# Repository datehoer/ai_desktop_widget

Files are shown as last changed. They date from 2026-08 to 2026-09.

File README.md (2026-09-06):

# Codex Usage Widget

**English** | [简体中文](README.zh-CN.md)

A desktop Codex status display built with an ESP32-S3 NANO and a 1.54-inch ST7789 TFT. Track weekly usage, active tasks, and room conditions; enjoy a graffiti-style **HH:MM:SS flip clock** when your tasks are done.

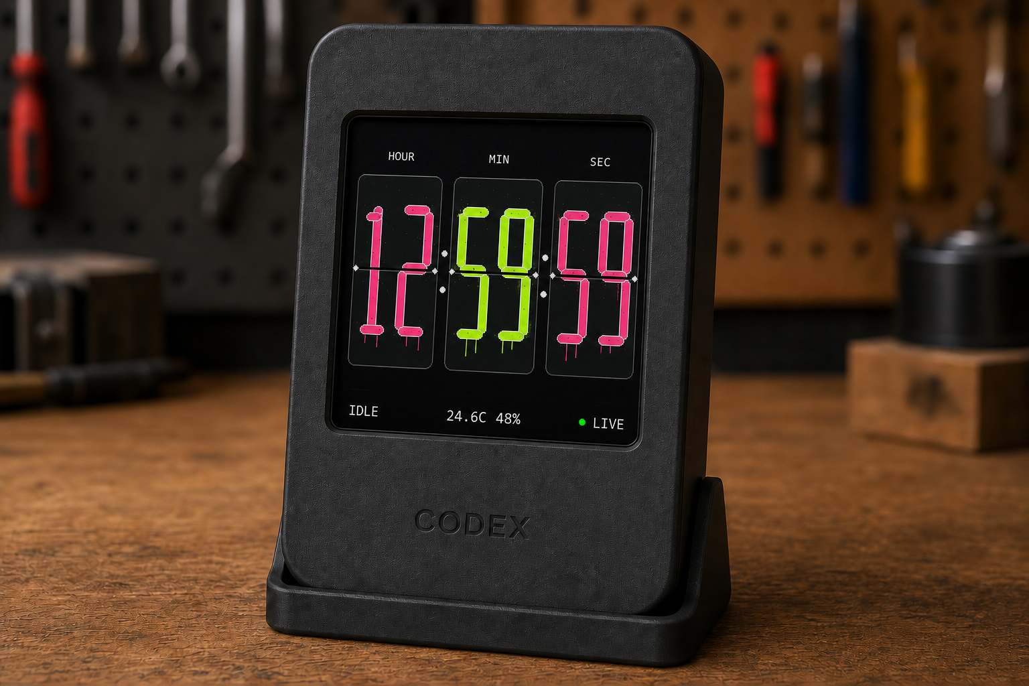
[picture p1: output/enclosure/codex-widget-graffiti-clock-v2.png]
Codex Usage Widget with the three-pair HH:MM:SS flip clock


*AI-generated product concept render of the updated clock interface. The animation preview below is generated from the firmware drawing code; neither image is a photograph of the running device.*

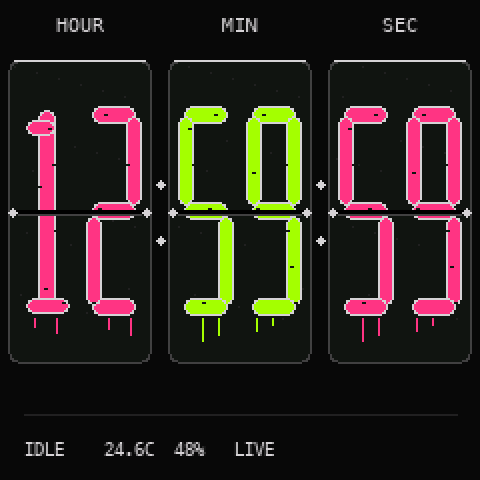
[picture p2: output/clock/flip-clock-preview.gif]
Flip animation generated from the firmware drawing code


The seconds card flips every second. The hour and minute cards join in when their values change. Each flip takes about **650 ms**: the old upper half folds toward the hinge, then the new lower half unfolds with changing shading. Frames are composed in memory before reaching the display. Bridge requests run in a background task so HTTP timeouts do not freeze the clock.

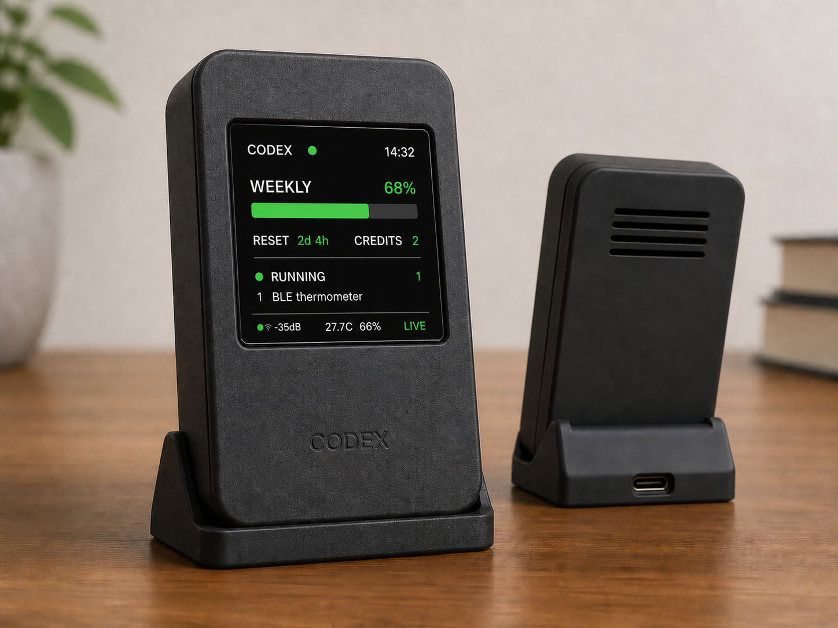
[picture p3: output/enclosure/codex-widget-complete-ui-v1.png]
Task status and BLE room readings, product concept render


## Features

- Weekly Codex usage, reset countdown, and available reset credits.
- Active task count and up to two real task titles, including common Simplified Chinese characters.
- Three paired flip cards for hours, minutes, and seconds, with pink and lime graffiti numerals.
- Automatic switching between the task dashboard, idle clock, and offline clock.
- Temperature and humidity from an optional Xiaomi `LYWSD03MMC` BLE thermometer.
- Wi-Fi setup and later configuration from a browser, with settings saved in NVS.
- A macOS background service that waits for external project volumes and the configured proxy at login.
- Printable enclosure files and a local 3D viewer with mesh diagnostics, assembly inspection, and collision simulation.

The hardware has been tested with an **ESP32-S3 NANO with 16 MB flash and 8 MB PSRAM**, and a **240×240 ST7789 SPI display**. The setup guide below targets macOS.

## Recent changes

| Area | Current behavior |
| --- | --- |
| Flip clock | HH:MM:SS replaces the four-digit HH:MM layout; actual half-page projection replaces the old covering-band transition. |
| Rendering | A 650 ms animation updates changed cards from offscreen buffers; HTTP requests execute separately from rendering. |
| Timekeeping | Minute, hour, and midnight rollovers flip together. Initial NTP sync and clock jumps snap to the current time without replaying missed seconds. |
| Offline fallback | After at least 30 seconds without fresh data and a confirmed request failure, the display switches to `CLOCK / STALE`. Invalid or stale HTTP 200 payloads do not count as recovery. |
| Task tracking | Unfinished rollout activity expires after 30 minutes without file updates by default, preventing abandoned tasks from remaining active indefinitely. |
| Reset countdown | Refreshes independently after time synchronization instead of waiting for the next full status render. |
| Enclosure and viewer | The v7 rear shell repairs non-manifold rail stops; the viewer checks mesh topology and provides an aligned front/rear shell inspection with electronics proxies. |

## How it works

The ESP32 does not sign in to Codex or store ChatGPT credentials. A Node.js bridge on the Mac starts a local `codex app-server`, reads account and task information, and exposes a compact LAN HTTP endpoint. The device polls every **5 seconds by default**, configurable from 2 to 60 seconds.

```mermaid
flowchart LR
    A["Codex Desktop / CLI"] --> B["codex app-server"]
    B --> C["Mac Node.js bridge :8787"]
    C -->|"Wi-Fi / JSON"| D["ESP32-S3 NANO"]
    D -->|"SPI"| E["ST7789 240×240 TFT"]
    F["LYWSD03MMC thermometer"] -->|"BLE"| D
```

The bridge uses `account/rateLimits/read` for quota windows, reset times, and credits, and `thread/list` for task metadata and local rollout paths. It reads rollout lifecycle events to determine whether a task is still running. The HTTP endpoint serves its latest snapshot immediately while refreshing Codex data in the background.

References: [Codex CLI documentation](https://learn.chatgpt.com/docs/codex/cli) and [Codex App Server documentation](https://learn.chatgpt.com/docs/app-server).

## Display modes

| Display | Trigger | Meaning |
| --- | --- | --- |
| Task dashboard · `LIVE` | Valid fresh status with `runningCount > 0` | Shows quota and active tasks. |
| Flip clock · `IDLE / LIVE` | Valid fresh status with `runningCount == 0` | No task is currently executing; the bridge is connected. |
| Existing display · `STALE` | A request fails or returns invalid/stale data | Temporarily retains the previous display while retrying. |
| Flip clock · `CLOCK / STALE` | No fresh status for at least 30 seconds, with failure confirmed | Offline fallback; time and BLE readings remain available after initial clock sync. |
| `NO DATA` | No successful status received yet | Waits for the bridge; persistent failure leads to the offline clock. |
| `SETUP MODE` | Missing configuration, startup Wi-Fi failure, or holding BOOT for 4 seconds | Opens the configuration hotspot. |

**`IDLE` means idle, not disconnected.** A completed assistant reply can leave no running task and switch the display to the clock. A new running task brings back the dashboard on a subsequent refresh. Bridge refresh and device polling each have their own interval, so a change is not instantaneous.

The 30-second fallback uses a monotonic timer. Merely waiting for a configured 60-second poll does not count as a failure. Detection can occur later than 30 seconds if a request is still pending or the next poll has not started. Responses with `ok=false`, `stale=true`, or an invalid task count cannot revive stale tasks.

NTP establishes the clock initially. After that, it keeps time if connectivity is lost; before initial sync, the clock shows placeholders. Time jumps are applied directly. The existing startup Wi-Fi recovery flow still enters setup mode if the configured network cannot be reached.

## 1. Requirements

### Hardware

- ESP32-S3 NANO with soldered headers, 16 MB flash, and 8 MB PSRAM.
- 1.54-inch TFT with ST7789 driver, SPI interface, 240×240 resolution, and soldered headers.
- Eight female-to-female jumper wires.
- A USB-C cable that supports data transfer.
- Optional breadboard; direct jumper connections work for initial testing.
- Optional Xiaomi `LYWSD03MMC` BLE thermometer; no additional wiring is required.

The pin assignment and flash settings match this hardware. Adjust [firmware/platformio.ini](firmware/platformio.ini) for a different board, flash size, display driver, or resolution.

### Software

- macOS, Git, Node.js, npm, Python 3.12, and [uv](https://docs.astral.sh/uv/).
- Node.js 20 or later for the bridge; `.nvmrc` pins **22.22.1** for the project, including the viewer tooling.
- Codex CLI installed and signed in with ChatGPT.
- A 2.4 GHz Wi-Fi network that allows the Mac and ESP32 to reach each other.

## 2. Wire the display with power disconnected

Disconnect USB before wiring. Check every connection before powering the board.

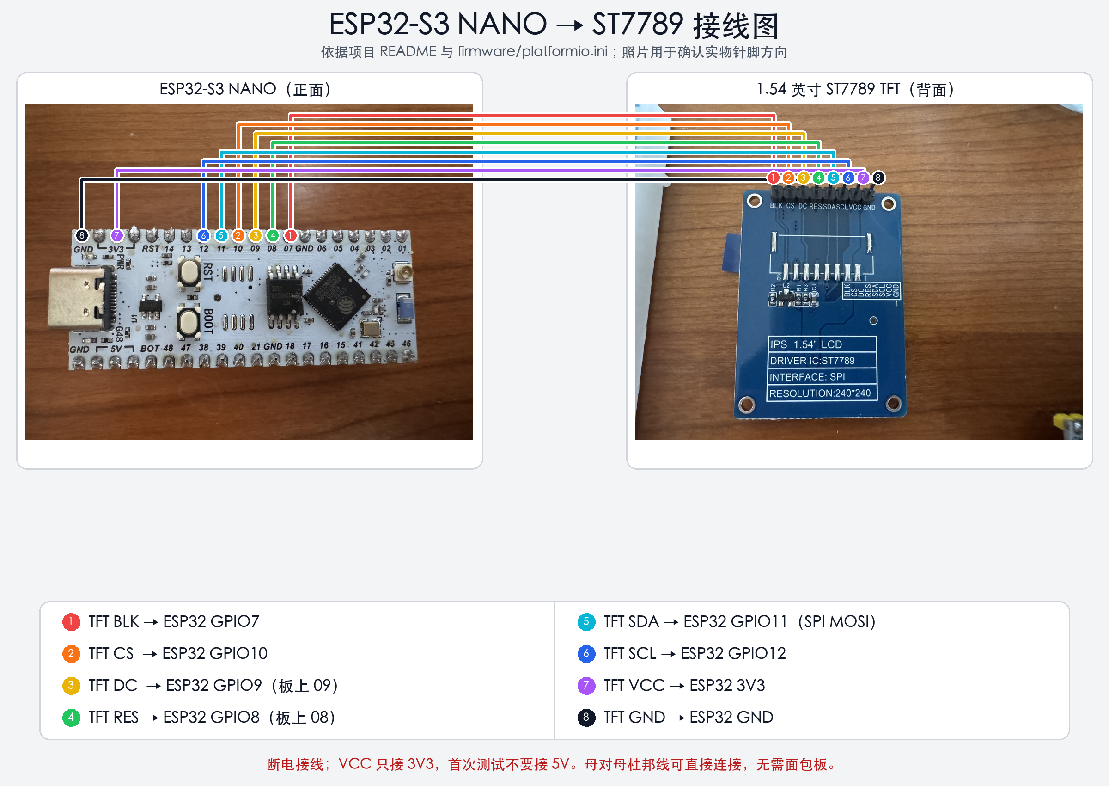
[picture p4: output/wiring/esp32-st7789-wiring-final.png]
ESP32-S3 NANO to ST7789 wiring


| ST7789 TFT | ESP32-S3 NANO | Function |
| --- | --- | --- |
| `BLK` | `GPIO7` | Backlight |
| `CS` | `GPIO10` | SPI chip select |
| `DC` | `GPIO9` | Data/command; printed as `09` on the board |
| `RES` | `GPIO8` | Display reset; printed as `08` |
| `SDA` | `GPIO11` | SPI MOSI, not I²C SDA |
| `SCL` | `GPIO12` | SPI clock |
| `VCC` | `3V3` | 3.3 V supply |
| `GND` | `GND` | Ground |

Connect `VCC` to `3V3`. Verify the actual silkscreen rather than assuming the pin order from viewing direction. Insert connectors fully and check for loose contacts. Wire colors do not determine their function.

## 3. Get the project

```bash
git clone https://github.com/datehoer/ai_desktop_widget.git ai_desktop_usage_widget
cd ai_desktop_usage_widget
```

For a ZIP download, extract it and enter the directory containing `README.md`, `package.json`, and `firmware/`.

```text
ai_desktop_usage_widget/
├── README.md                    # English guide
├── README.zh-CN.md              # Simplified Chinese guide
├── bridge/
│   ├── src/                     # Mac bridge and rollout tracking
│   └── test/                    # Node.js tests
├── firmware/
│   ├── include/
│   │   ├── flip_clock.h         # Portable animation geometry and time transitions
│   │   └── secrets.example.h    # Optional legacy configuration migration
│   ├── src/
│   │   ├── main.cpp             # TFT UI and background status worker
│   │   ├── ble_thermometer.cpp  # BLE sensor reader
│   │   ├── device_config.cpp    # NVS persistence and time zones
│   │   └── config_portal.cpp    # Hotspot and LAN configuration pages
│   ├── test/                   # Native flip-clock tests
│   └── platformio.ini
├── viewer/                     # Local model / G-code viewer and mesh diagnostics
├── output/
│   ├── clock/                  # Firmware-rendered animation preview
│   ├── enclosure/              # OpenSCAD, STL, and product renders
│   └── wiring/                 # Wiring illustration
├── scripts/                    # macOS background service helpers
├── package.json
├── pyproject.toml
└── uv.lock
```

## 4. Check Codex CLI

If needed, install with the macOS/Linux command from the [official Codex CLI guide](https://learn.chatgpt.com/docs/codex/cli):

```bash
curl -fsSL https://chatgpt.com/codex/install.sh | sh
```

Then verify and sign in:

```bash
codex --version
codex
```

Sign in with ChatGPT if needed, exit the interactive session, and check that App Server starts:

```bash
codex app-server
```

If the process stays running without an immediate error, stop it with `Ctrl+C`. The bridge starts its own instance, so a second manually started instance is unnecessary.

## 5. Prepare Node.js

With nvm installed:

```bash
nvm install
nvm use
node --version
npm --version
npm test
```

The bridge uses only Node.js built-in modules and has no third-party npm runtime dependencies. The separate viewer has its own dependencies.

## 6. Start the Mac bridge

```bash
npm start
```

Example output:

```text
Codex Usage Bridge listening on http://0.0.0.0:8787
ESP32 URL: http://192.168.1.100:8787/api/status
```

Use the printed **LAN IPv4 URL** in the device configuration. `localhost` and `127.0.0.1` refer to the ESP32 itself when entered on the device.

Leave the bridge running and check it from another terminal:

```bash
curl http://127.0.0.1:8787/healthz
curl http://127.0.0.1:8787/api/status
```

A successful status includes fields such as these; values are illustrative:

```json
{
  "ok": true,
  "stale": false,
  "quota": {
    "weekly": {
      "usedPercent": 7,
      "resetsAt": 1780000000
    }
  },
  "resetCredits": 0,
  "runningCount": 1,
  "running": [
    { "title": "Build the desktop widget" }
  ]
}
```

### Bridge environment variables

| Variable | Default | Purpose |
| --- | --- | --- |
| `PORT` | `8787` | HTTP port |
| `HOST` | `0.0.0.0` | HTTP bind address |
| `REFRESH_MS` | `5000` | Background refresh interval in milliseconds |
| `RUNNING_STALE_MS` | `1800000` | Expire active rollouts after this period without file updates; `0` disables expiry |
| `CODEX_BIN` | `codex` | Custom Codex CLI path |
| `DEBUG_CODEX_BRIDGE` | Unset | Set to `1` to show App Server logs |

## 7. Prepare Python and PlatformIO

uv manages Python 3.12 and the pinned PlatformIO **6.1.19** environment:

```bash
uv sync
uv run platformio --version
```

This creates `.venv`; a separate Conda environment is unnecessary.

If dependency downloads require a local proxy, configure it in the current terminal, using your own address:

```bash
export https_proxy=http://127.0.0.1:7890
export http_proxy=http://127.0.0.1:7890
export all_proxy=http://127.0.0.1:7890
export no_proxy=
uv sync
uv run platformio run -d firmware
```

After downloading, use a clean terminal or appropriate proxy bypass settings for LAN traffic.

## 8. Prepare first-time configuration

Wi-Fi credentials are configured in a browser and stored in NVS. A new device does not need `secrets.h`. Prepare:

- Your 2.4 GHz Wi-Fi SSID and password.
- The Mac bridge LAN URL, such as `http://192.168.1.100:8787/api/status`.
- A time zone; choose the Shanghai / UTC+8 option for China.
- A polling interval from 2 to 60 seconds; the default is 5 seconds.

The setup screen shows:

```text
SETUP MODE
Codex-Widget-XXXX
Password: codexsetup
192.168.4.1
```

Connect a phone or computer to this temporary hotspot. Open the captive portal, or visit `http://192.168.4.1/` manually. Save the configuration to reboot the device.

The setup page currently uses Chinese labels. Existing devices with legacy `secrets.h` settings can connect once and migrate those settings into NVS automatically.

## 9. Identify the connected ESP32

Use a data-capable USB-C cable, then list ports:

```bash
uv run platformio device list
```

A macOS port may look like `/dev/cu.usbmodem11201`; substitute your actual port in all later commands. A power LED alone does not confirm that the firmware is running.

When multiple ESP32 boards are attached, match the USB serial number and startup log. This project prints **`[boot] Codex Usage Widget`**. Do not select a board solely by port numbering or the shared `USB JTAG/serial debug unit` description.

## 10. Build and test the firmware

```bash
uv run platformio run -d firmware
```

The first build downloads TFT_eSPI, ArduinoJson, and U8g2_for_TFT_eSPI, including the compiled WenQuanYi Chinese font.

The current build uses approximately **21.7% static RAM** and **26.7% flash**. Flip buffers allocate another **150 KiB at runtime**, preferably in PSRAM. If buffer allocation fails, the clock falls back to static updates and reports it in the serial log.

Run the portable animation tests on the Mac with a C++ compiler installed:

```bash
c++ -std=c++11 -Wall -Wextra -Werror -Ifirmware/include \
  firmware/test/flip_clock_test.cpp -o /tmp/flip-clock-test
/tmp/flip-clock-test
```

These check page geometry, every daily second rollover, midnight, time jumps, and RGB565 shading.

## 11. Upload the firmware

Specify the verified target port:

```bash
uv run platformio run -d firmware \
  --target upload \
  --upload-port /dev/cu.usbmodem11201
```

A successful upload ends with messages such as:

```text
Hash of data verified.
Hard resetting via RTS pin...
[SUCCESS]
```

If it remains at `Connecting...`, hold **BOOT**, briefly press **RST**, release **BOOT**, and retry.

The project also includes a USB-JTAG recovery environment:

```bash
uv run platformio run -d firmware \
  -e esp32-s3-nano-jtag \
  --target upload
```

## 12. Read the serial log

```bash
uv run platformio device monitor \
  --port /dev/cu.usbmodem11201 \
  --baud 115200
```

Typical output:

```text
[boot] Codex Usage Widget
[boot] initialising TFT on SPI3/HSPI
[boot] TFT ready
[clock] HH:MM:SS flip buffers ready, duration 650ms
[config] loaded from NVS
[wifi] configured SSID found: your-wifi (-42 dBm)
[wifi] connected: 192.168.1.155
[config] bridge: http://192.168.1.100:8787/api/status
[config] hold BOOT for 4s to reconfigure
[display] live status
[task] title: Build the desktop widget
[ble] thermometer reader started
```

Press `Ctrl+C` to leave the monitor. This does not stop the ESP32.

## 13. Read the dashboard and room sensor

The initial sequence is: backlight on, setup if required, Wi-Fi connection, clock synchronization, then the task dashboard or idle clock according to the bridge status.

| Area | Contents |
| --- | --- |
| Header | `CODEX`, bridge status dot, current time |
| `WEEKLY` | Used weekly quota and progress bar |
| `RESET` | Time until the weekly quota resets |
| `CREDITS` | Available reset credits, or `--` if unavailable |
| `RUNNING` | Number of unfinished tasks detected by the bridge |
| Task list | Up to two real titles, truncated with `...` when necessary |
| Footer | Wi-Fi RSSI, BLE temperature/humidity, and `LIVE / STALE` |
| Idle clock | `HOUR / MIN / SEC` cards, room readings, and connection status |

The BLE reader scans roughly once per minute for the strongest nearby device named `LYWSD03MMC`, connects briefly to read temperature, humidity, and battery information, then disconnects. The screen displays temperature and humidity. Brief connections reduce the time the reader occupies the sensor connection used by an existing Xiaomi gateway.

Before the first dashboard reading, the footer can show `BLE...`; an absent sensor shows `BLE --`, and a connection/read failure shows `BLE ERR`. Readings older than three minutes remain visible but turn amber on the dashboard. The idle clock uses `ROOM ...` or `ROOM --` before a reading is available.

## 14. Daily use and configuration

Power the ESP32, keep the Mac and device on the same LAN, and start the bridge:

```bash
nvm use
npm start
```

Keep the Mac awake and the bridge running, or install the background service described below.

When the ESP32 is connected, change Wi-Fi, bridge URL, time zone, or polling interval at [codex-widget.local](http://codex-widget.local/). If mDNS is unavailable, use the IP printed after `[config] LAN page:` in the serial log. Saving settings reboots the device.

If the original Wi-Fi is unreachable, hold **BOOT for 4 seconds** to enter the temporary setup hotspot. Reflashing is needed for firmware or pin changes, not routine network configuration.

If the Mac's DHCP address changes, update the bridge URL in this page. A DHCP reservation for the Mac avoids repeated address changes. The device's `.local` configuration address does not automatically discover the bridge.

### macOS background service

The user-level `launchd` service starts at login and restarts the bridge after a crash. Its small launcher lives on the system disk and waits for the project volume and configured proxy before starting, including projects located under `/Volumes/...`.

The installer defaults HTTP, HTTPS, and ALL proxy settings to `http://127.0.0.1:7890`, with bypasses for localhost, LAN addresses, and `.local` names. Use a running proxy at that address or override it:

```bash
nvm use
npm run service:install

# If your proxy uses a different port:
CODEX_WIDGET_PROXY='http://127.0.0.1:7891' npm run service:install
```

Check status or remove the service:

```bash
npm run service:status
npm run service:uninstall
```

Logs:

```text
~/Library/Logs/CodexUsageWidget/bridge.log
~/Library/Logs/CodexUsageWidget/bridge.error.log
```

Do not also run `npm start` when the service already owns port 8787. Reinstall the service after moving the repository or changing Node/Codex executable paths. The current installer assumes a local proxy; use the manual bridge startup if you do not have one.

## 15. Troubleshooting

| Symptom | Checks |
| --- | --- |
| No backlight | Check `VCC → 3V3`, `GND → GND`, `BLK → GPIO7`, and USB power. |
| Backlight but no image | Verify CS/DC/RES/SDA/SCL, ST7789 SPI at 240×240, and the repository's PlatformIO configuration. |
| Reboot / `StoreProhibited` during TFT init | Preserve `-D USE_HSPI_PORT=1`, which selects the required SPI3/HSPI path on this hardware. |
| No serial port | Try a known data cable and another USB port, list devices again, or enter BOOT/RST download mode. |
| Wi-Fi fails | Check the exact SSID/password, 2.4 GHz availability, client isolation, guest-network restrictions, and device/MAC limits. Startup connection failure opens setup mode. |
| Wi-Fi connected, but `NO DATA` | Check `npm run service:status` or the manual bridge, the device's bridge URL, macOS firewall, LAN reachability, and `/api/status`. A newly started bridge may return 503 before its first snapshot. |
| Repeated `STALE` | Check Mac sleep, Wi-Fi, bridge logs, and firewall. `[bridge] HTTP -11` usually indicates an HTTP timeout. Persistent failure leads to `CLOCK / STALE`. |
| `IDLE` after a reply finishes | Expected when there are no active tasks. `IDLE / LIVE` indicates a healthy connection; a new active task returns the dashboard after refresh. |
| Seconds change without flipping | Check for `[clock] HH:MM:SS flip buffers ready, duration 650ms`. An allocation failure uses static updates. Time sync/jumps also intentionally snap. Rebuild and upload if still running the old HH:MM firmware. |
| Project name instead of real task title | Compare the API's `title` field with `[task] title:` in the serial log. Build and upload current firmware. |
| Chinese missing or rendered as boxes | Check U8g2_for_TFT_eSPI and `u8g2_font_wqy14_t_gb2312b`, then rebuild. The font covers common GB2312 Simplified Chinese, not all Unicode or emoji. |
| Time remains placeholders | Check NTP access to `pool.ntp.org` / `time.cloudflare.com` and select the correct time zone in the configuration page. Supported DST zones switch automatically. |
| `RUNNING` differs from expectations | Allow bridge and device refreshes. Lifecycle events determine activity, with a default 30-minute no-update expiry controlled by `RUNNING_STALE_MS`. |
| PlatformIO download fails | Use your actual proxy address for dependency downloads, then restore appropriate LAN proxy bypass settings. |

The task tracker recognizes `task_started`, `task_complete`, `task_cancelled`, and `turn_aborted` rollout events. An old `task_started` without later file activity eventually expires instead of remaining active forever.

## 16. Security and limitations

- The ESP32 stores Wi-Fi settings in NVS without flash encryption enabled by default. The web configuration page does not echo the stored password.
- ChatGPT login credentials stay on the Mac. Do not commit real `secrets.h`, account files, or sensitive serial logs.
- The bridge and LAN configuration page are intended for a trusted LAN. The bridge listens on all interfaces by default without authentication; do not expose port 8787 to the public internet.
- The Mac must remain powered on with the bridge running for live task data.
- macOS and the specified ESP32-S3 NANO hardware have been tested; other operating systems require different serial and startup instructions.
- The bridge inspects the 30 most recently updated unarchived tasks. It counts those detected as active, returns up to four task summaries, and the TFT shows up to two titles.
- Chinese glyph coverage is limited to the bundled font. Codex App Server or rollout-format changes may require bridge updates.

## 17. Development and verification

For bridge changes:

```bash
npm test
```

For firmware changes:

```bash
c++ -std=c++11 -Wall -Wextra -Werror -Ifirmware/include \
  firmware/test/flip_clock_test.cpp -o /tmp/flip-clock-test
/tmp/flip-clock-test
uv run platformio run -d firmware
```

Then upload to the verified device port using the command in section 11. Restart a manual bridge after code changes, or reinstall the background service to update its configuration and restart it.

The HH:MM:SS update was compiled, passed the native flip tests and six bridge tests, and was uploaded to the identified project device. Startup confirmed the flip buffers were ready and live task data resumed. The GIF is a host-generated drawing preview; final motion on the physical TFT remains subject to its refresh characteristics.

## 18. Enclosure and local 3D viewer

The enclosure combines a black front frame, a smoke-translucent PETG rear shell, and a black stand tilted back 15°. Dimensions, printing guidance, assembly notes, and OpenSCAD export commands are in the [enclosure guide (Chinese)](output/enclosure/README.md).

Current versioned files:

| Part | File |
| --- | --- |
| Wider front frame | [front-black-v5-wide.stl](output/enclosure/front-black-v5-wide.stl) |
| Rear shell with manifold rail stops | [back-smoke-petg-v7-manifold.stl](output/enclosure/back-smoke-petg-v7-manifold.stl) |
| Matching wider stand | [stand-black-v5-wide.stl](output/enclosure/stand-black-v5-wide.stl) |
| Parametric source | [codex_widget_enclosure.scad](output/enclosure/codex_widget_enclosure.scad) |

The v7 rear shell joins the rail stops to the side rails with a 0.4 mm overlap to remove non-manifold edges. The viewer's internal assembly mode loads the current front/rear shells and electronics proxies. Its present depth calculation reports **0 mm remaining clearance**, so review actual connectors, cable bends, and a fit sample before treating the render as a confirmed hardware fit.

`viewer/` is a separate browser tool. Imported files are parsed locally and are not uploaded. It supports:

- STL, 3MF, OBJ, AMF, PLY, and STEP/STP model import, plus G-code paths and layer inspection.
- Multiple parts, automatic arrangement, canvas selection, move/rotate/scale controls, world/local coordinates, snapping, and W/E/R/Q shortcuts.
- Exact XYZ editing, centering, placing on the bed, duplicate/reset/delete, and assembly clearing.
- Dimensions, triangle counts, mesh counts, and plastic, translucent PETG, or metal appearances.
- Rapier gravity, friction, and collisions with the print bed and other parts.
- Background mesh checks for separate shells, non-manifold edges, holes, inconsistent winding, duplicate triangles, and degenerate triangles.
- Internal assembly inspection with aligned front/rear shells and TFT/ESP32 proxies, plus a G-code example.

Topology checks help identify mesh defects; they do not replace slicer checks for thin walls, overhangs, or material shrinkage.

```bash
npm run viewer:install
npm run viewer:dev
```

Open [localhost:4173](http://localhost:4173/). Build and preview production output with:

```bash
npm run viewer:build
npm run viewer:preview
```

The viewer uses Online3DViewer, GCode Preview, Three.js, and Rapier. Production output includes the two front/rear STL assets used by the internal assembly inspector.

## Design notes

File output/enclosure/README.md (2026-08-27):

# Codex Usage Widget：方案 3 可打印外壳

选定方向：黑色前框 + 烟灰透明 PETG 后壳 + 黑色 15° 底座。

## 文件

- `codex_widget_enclosure.scad`：完整参数模型与爆炸预览
- `front-black.scad`：黑色前框单件导出入口
- `back-smoke-petg.scad`：烟灰透明后壳单件导出入口
- `stand-black.scad`：黑色底座单件导出入口
- `full-assembly-collision-check.scad`：完整外壳与底座的实体穿模检查
- `front-black.stl`：可直接切片的黑色前框
- `back-smoke-petg.stl`：可直接切片的烟灰透明后壳
- `back-smoke-petg-v7-manifold.stl`：修复 ESP32 导轨止挡坏边后的推荐打印版本
- `stand-black.stl`：可直接切片的黑色底座
- `design-option-3.png`：选定的外观方向
- `front-preview.png`、`back-preview.png`、`stand-preview.png`：OpenSCAD 实体渲染预览

## 结构

### 黑色前框

- 50 × 78 mm 正面，4 mm 圆角；相对原版四周各外扩 2 mm
- 30.4 × 31.4 mm 屏幕开窗
- 屏幕黑边约 1 mm，开窗四周压住约 0.8 mm，预计露出约 0.2 mm 黑边
- 主体壁厚 2.4 mm、面板 2.6 mm，内部定位唇 1.4 mm，满足壁厚大于 1.2 mm 的上传要求
- TFT 使用四个盲孔支撑柱，从背面固定，因此正面无螺丝
- 前框只保留 6 mm 短柱，柱端带 1 mm 锥形导角，不再用四根长柱插入后壳
- 四个锁紧点移到更内侧的 ±10 × ±29 mm，避免盖板倾斜时撞到后壳边沿
- 后壳空心导管前端为 Ø7.4 mm 喇叭口，接收前框 Ø4.2 mm 锥头并自动找正
- 合盖后的正面压力由整圈 2.4 mm 后壳边沿承担，四个锥座负责抗横向位移
- 建议用四颗 M2 × 30 mm 螺丝从背面穿过导管锁入前框短柱
- 周边定位唇每侧预留 1 mm，入口再渐缩 0.5 mm，可先自校正再完全合盖

### 烟灰透明后壳

- 内部净深 30 mm
- 后板 2.2 mm，侧壁 2.4 mm
- 与前框装配后的总厚度约 34.8 mm
- ESP32 采用侧边导轨和底部止挡定位
- v7 将底部止挡与两侧导轨改为 0.4 mm 实体搭接，消除两条非流形坏边，不占用 PCB 有效空间
- 两侧理线柱让 8 根 80 mm 母对母杜邦线形成平缓 U 形回路
- 后背板下方中央 USB-C 开口约 9.8 × 5.2 mm，中心距机身底边 10 mm
- 背面有三条通风孔、RST/BOOT 访问孔和四个 M2 螺丝孔

### 底座

- 15° 后倾
- 60 × 60 mm 稳定底盘，插槽按 34.8 mm 外壳厚度更新
- 斜底托、32 mm 高后靠背和 11 mm 前挡边共同锁定 15° 倾角
- 两端侧板防止机身横向滑出；插槽每侧预留 0.6 mm 打印装配间隙
- 后向开放式走线槽对应后壳侧的 USB-C 接口，线缆从底座背面引出
- 独立打印，可不使用底座而让设备靠墙放置

## 当前实测参数

- TFT PCB：32 × 44 × 1.6 mm
- 屏幕：约 32 × 33 mm
- 屏幕与 PCB 总厚度：约 4 mm
- 屏幕高出 PCB 正面：约 2.4 mm
- 屏幕距 PCB 长边两端：约 5.4 mm，视为居中
- TFT 安装孔：约 Ø2 mm
- 暂按孔边缘距 PCB 边缘 1 mm解释，孔中心距为 28 × 40 mm
- ESP32-S3 NANO：52 × 20.5 mm
- 开发板原生 USB-C 位于 20.5 mm 短边中央；外壳采用背板接口孔，内部需短转接线连接
- 杜邦线：8 根母对母，长度约 80 mm，保留黑色绝缘胶壳
- 接线后的硬件厚度：约 22–23 mm

## 建议打印参数

| 零件 | 材料 | 放置方向 | 建议参数 |
| --- | --- | --- | --- |
| 前框 | 黑色 PLA/PETG | 正面贴平台 | 0.2 mm 层高、4 周壁、20% 填充 |
| 后壳 | 烟灰透明 PETG | 背面贴平台，开口朝上 | 0.2 mm 层高、4 周壁、0–15% 填充 |
| 底座 | 黑色 PLA/PETG | 底面贴平台 | 0.2 mm 层高、4 周壁、20% 填充 |

透明 PETG 的实际效果会是烟灰半透明，不会像渲染图那样清澈。减少填充、统一走线方向并降低打印速度，可以让内部轮廓更容易看见。

## 导出 STL

已通过 OpenSCAD 2026.06.12 导出三个 STL，并完成 CGAL 实体渲染检查。三个零件均为封闭流形，未报告几何错误，可直接导入切片软件。

导出后的模型包围尺寸：

- 前框（包含 6 mm 短锥柱）：50 × 78 × 8.6 mm
- 后壳：50 × 78 × 32.2 mm
- 底座：约 60 × 60 × 34 mm

装配碰撞检查：

- 前壳与后壳按 2.6 mm 深度偏移合盖，实体交集为空
- 完整外壳按 15° 插入底座后，实体交集为空
- 底座插槽在外壳两侧各保留 0.6 mm 打印装配间隙

如修改了参数，可在本目录重新执行：

命令行方式：

```bash
openscad -o front-black.stl front-black.scad
openscad -o back-smoke-petg.stl back-smoke-petg.scad
openscad -o stand-black.stl stand-black.scad
```

## 首次样件复核

正式打印前建议先切一段 8–10 mm 高的低成本装配样条，检查：

1. TFT 四孔中心距到底是 28 × 40 mm，还是之前的“1 mm”指孔中心到边缘。
2. 30 mm 内部净深能否让黑色杜邦母头自然转弯。
3. USB-C 开口的高度与开发板实际固定位置是否一致。
4. 烟灰后壳与黑色前框的 0.3 mm 配合间隙是否适合当前打印机。

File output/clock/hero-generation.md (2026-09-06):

# HH:MM:SS product render

Generated with the built-in `image_gen` tool on 2026-09-06.

- Output: [codex-widget-graffiti-clock-v2.png](../enclosure/codex-widget-graffiti-clock-v2.png)
- Enclosure reference: [previous product render](../enclosure/codex-widget-graffiti-clock-v1.png)
- Screen reference: [firmware drawing frames](flip-clock-frames.png), leftmost frame only
- Motion preview: [flip-clock-preview.gif](flip-clock-preview.gif)

The product render is an AI-generated concept image. The GIF and frame strip use the firmware's drawing and flip projection code with a host bitmap adapter; text and primitive rasterization can differ from the TFT library. These assets are not photographs or screen recordings of the device.

## Final prompt

```text
Use case: precise-object-edit / product-mockup.
Asset type: GitHub README hero product concept render, landscape 1536x1024.
Input 1 is the edit target: existing black Codex desktop widget on its tilted black stand on a warm wooden workbench. Preserve its enclosure, recessed square LCD, engraved CODEX word, stand, viewpoint, workshop background, realistic materials and lighting.
Input 2 is the authoritative updated screen-layout reference: a horizontal strip of FIVE ANIMATION FRAMES. Use ONLY the LEFTMOST square frame as the static screen content, NOT the whole strip. It reads 12:59:59.
Primary request: regenerate the product render with the current firmware's HH:MM:SS display accurately replacing the old FOUR single-digit cards. The screen must have EXACTLY THREE adjacent tall flip cards; EACH card contains TWO digits. The three cards read "12", "59", "59", with thin colon dots BETWEEN cards. Above the cards, small plain white uppercase labels exactly "HOUR", "MIN", "SEC". Pink digits on the first card, lime-green digits on the middle card, pink digits on the last card. Digits are narrow straight segmented numerals with pale outlines, a few paint chips and drips, matching reference 2 closely; do not use the old rounded poster lettering from image 1.
Each paired card is divided into upper and lower halves by a crisp horizontal black hinge at its midpoint, with small silver pivot dots at its sides, subtle page thickness and natural shadow. This is a flat LCD showing an animated mechanical-flip metaphor, not a physical split-flap mechanism projecting out of the device.
At bottom of display show one clean readable status line exactly: left "IDLE", center "24.6C 48%", right a small green dot and "LIVE". Maintain spacious layout matching the LEFTMOST square of reference 2. Fit the entire new interface inside the EXISTING display aperture with realistic perspective, including all six digits and all labels. No additional text outside the device. No extra devices, arrows, captions, badges, watermark, borders, or diagram panels. Finished polished photorealistic concept render suitable for project documentation.
```

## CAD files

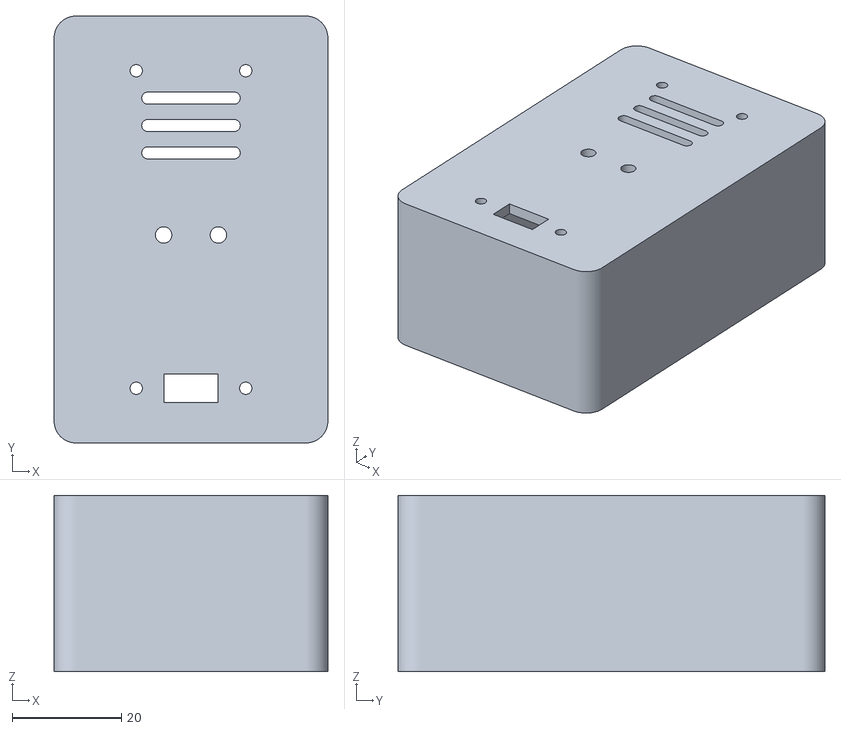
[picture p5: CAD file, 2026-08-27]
output/enclosure/back-smoke-petg-v7-manifold.stl
50.0 x 78.0 x 32.2

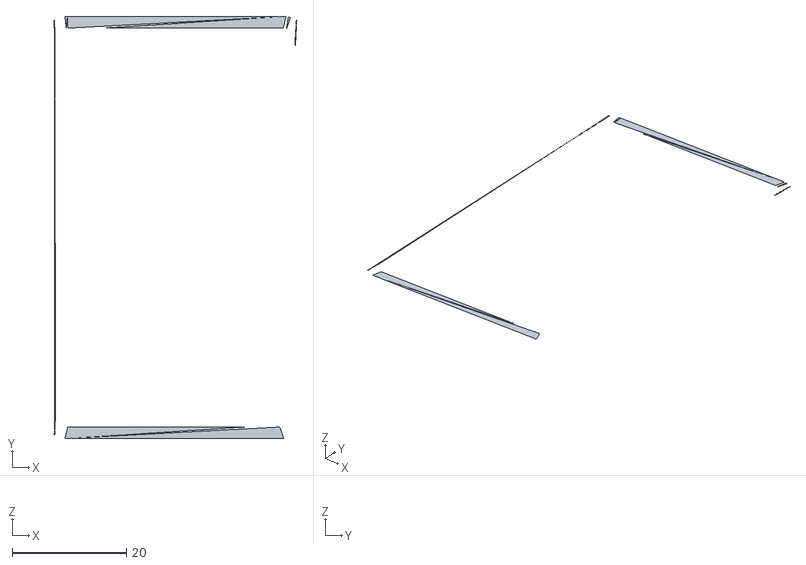
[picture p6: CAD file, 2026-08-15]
output/enclosure/collision-before.stl
42.4 x 74.0 x 0

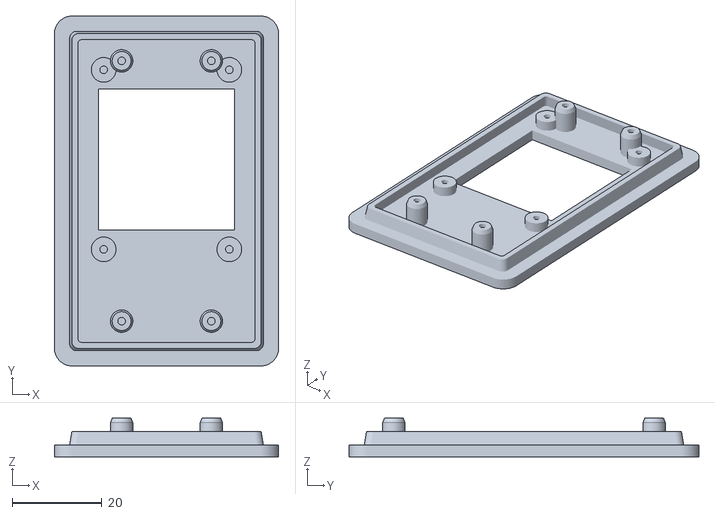
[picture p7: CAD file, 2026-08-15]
output/enclosure/front-black-v5-wide.stl
50.0 x 78.0 x 8.60

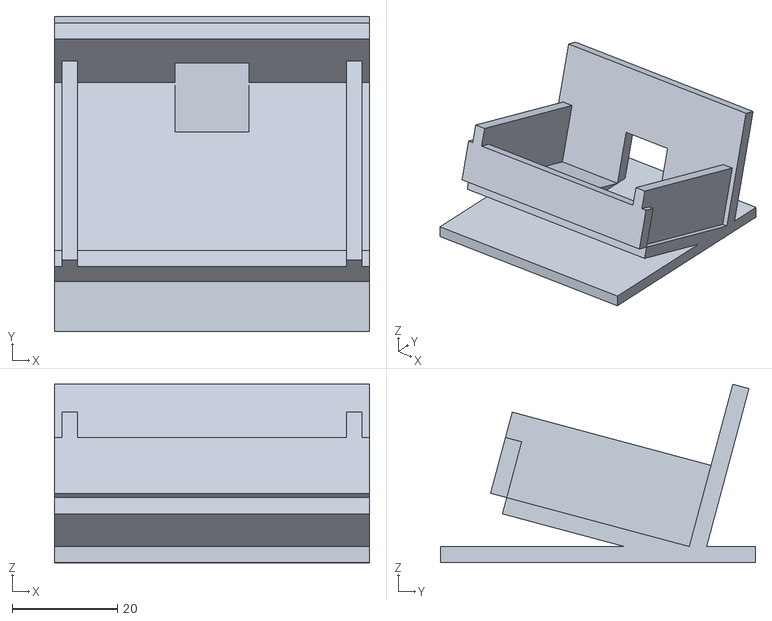
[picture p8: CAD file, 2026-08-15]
output/enclosure/stand-black-v5-wide.stl
60.0 x 60.0 x 34.0

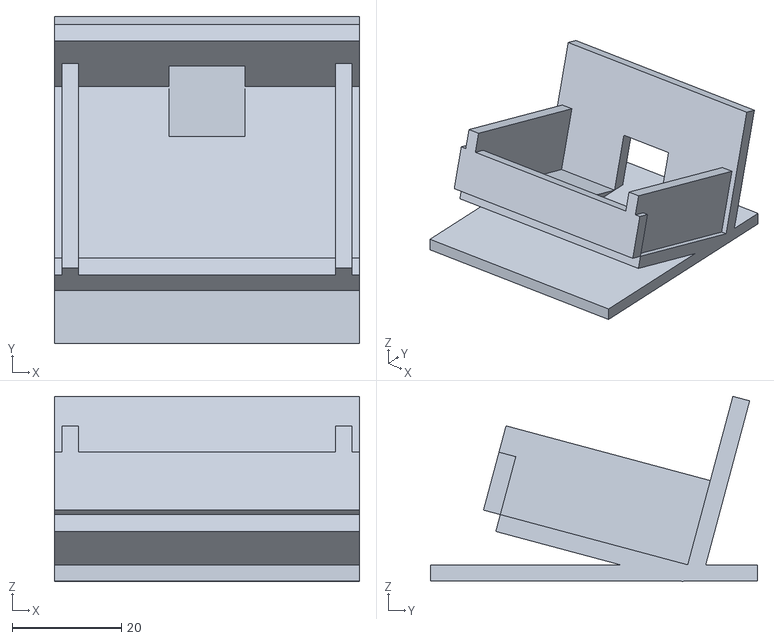
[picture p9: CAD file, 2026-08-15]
output/enclosure/stand-black-v4-back-port.stl
56.0 x 60.0 x 34.0

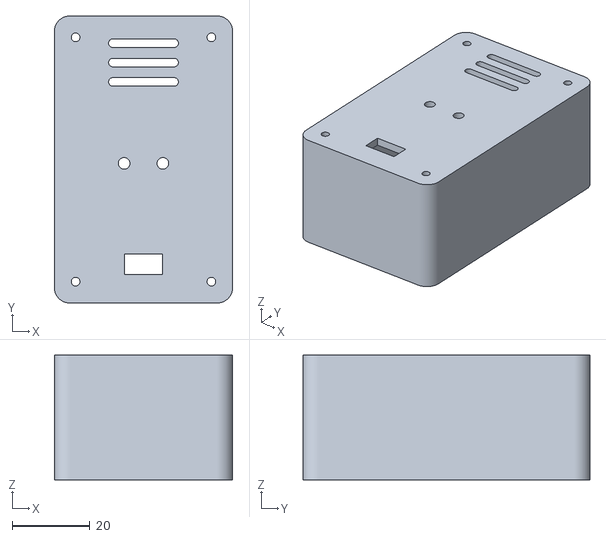
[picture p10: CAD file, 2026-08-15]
output/enclosure/back-smoke-petg-v3-post-clearance.stl
46.0 x 74.0 x 32.2

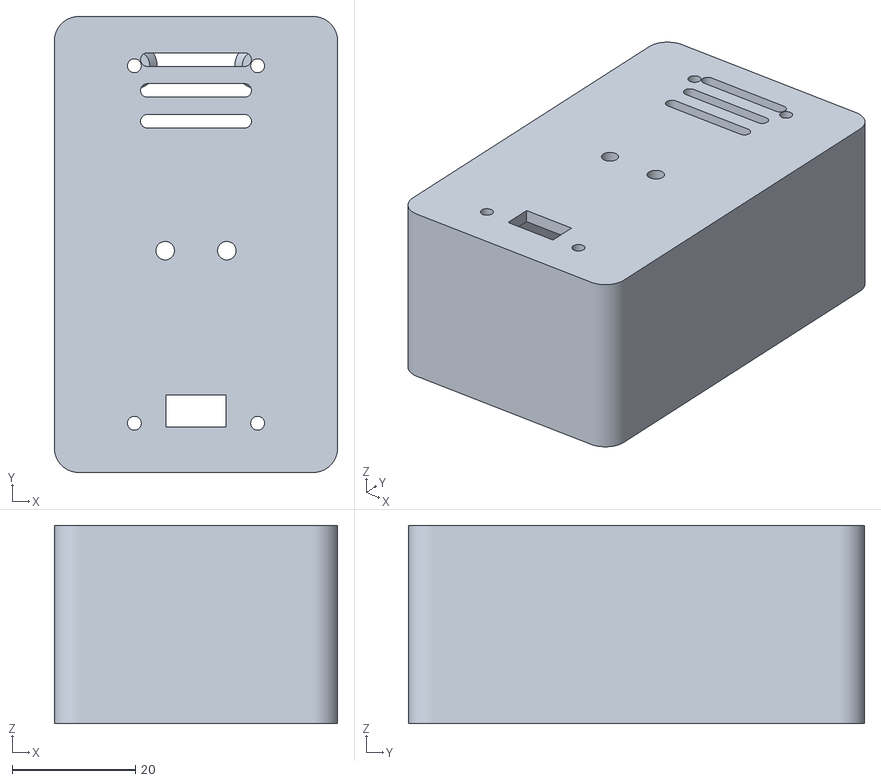
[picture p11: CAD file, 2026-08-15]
output/enclosure/back-smoke-petg-v5-conical-seat.stl
46.0 x 74.0 x 32.2

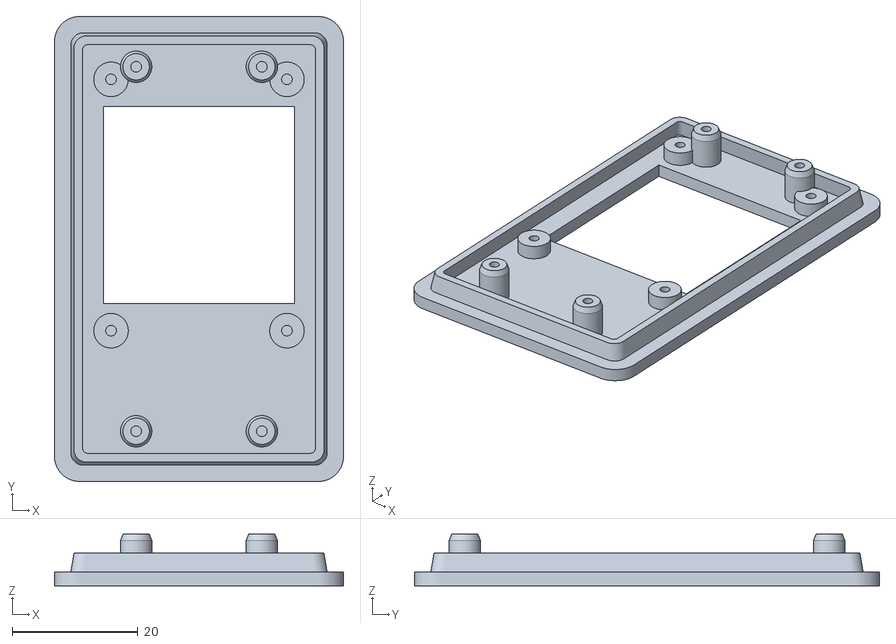
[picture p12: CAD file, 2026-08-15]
output/enclosure/front-black-v4-conical-seat.stl
46.0 x 74.0 x 8.20

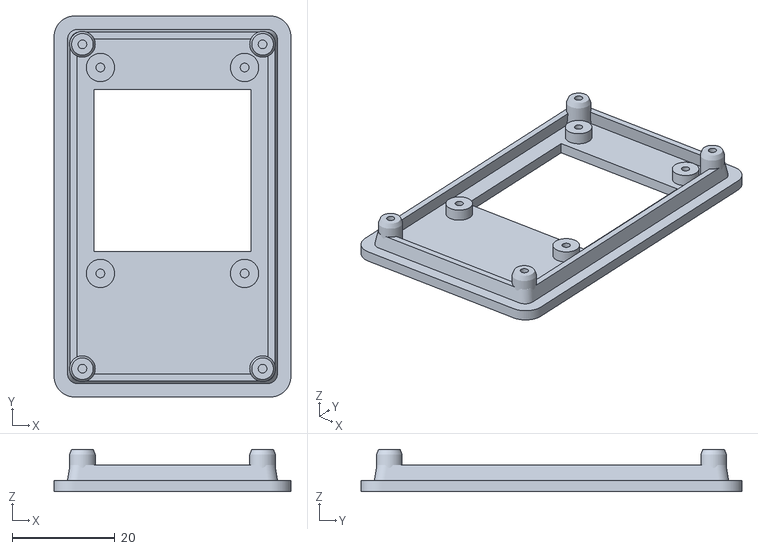
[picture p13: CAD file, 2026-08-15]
output/enclosure/front-black-v3-self-align.stl
46.0 x 74.0 x 8.20

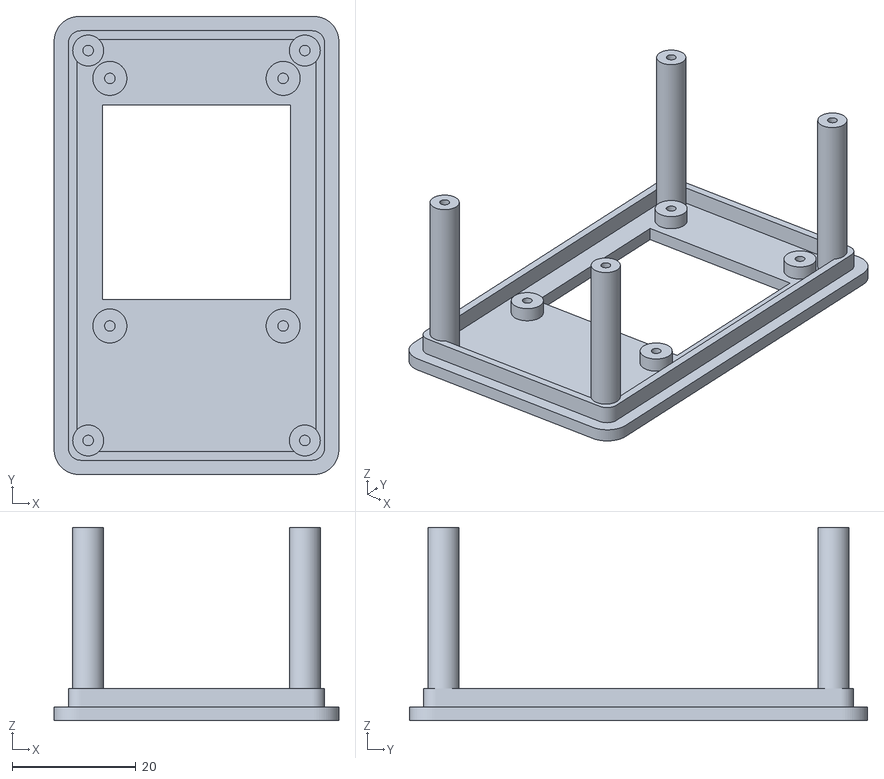
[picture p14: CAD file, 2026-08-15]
output/enclosure/front-black-v2-post-clearance.stl
46.0 x 74.0 x 31.2

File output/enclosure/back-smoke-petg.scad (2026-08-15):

part = "back";
include <codex_widget_enclosure.scad>;

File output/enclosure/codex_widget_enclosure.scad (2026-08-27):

// Codex Usage Widget — Option 3 printable enclosure
// Black front bezel + smoke PETG rear tub + removable 15-degree stand
// Units: millimetres
// Set part to: "assembly", "front", "back", or "stand".

$fn = 64;
selected_part = is_undef(part) ? "assembly" : part;

// ---------- Measured TFT module ----------
tft_pcb_w = 32;
tft_pcb_h = 44;
tft_pcb_t = 1.6;
tft_hole_d = 2;
tft_hole_edge_gap = 1;               // interpreted as hole edge -> PCB edge
tft_hole_center_inset = tft_hole_edge_gap + tft_hole_d / 2;
tft_hole_pitch_x = tft_pcb_w - 2 * tft_hole_center_inset; // 28
tft_hole_pitch_y = tft_pcb_h - 2 * tft_hole_center_inset; // 40

screen_w = 32;
screen_h = 33;
screen_black_border = 1;
screen_bezel_overlap = 0.8;
screen_window_w = screen_w - 2 * screen_bezel_overlap; // 30.4
screen_window_h = screen_h - 2 * screen_bezel_overlap; // 31.4
screen_end_margin_measured = 5.4;
tft_total_t = 4;
screen_above_pcb = tft_total_t - tft_pcb_t; // 2.4

// Module placement on the tall front face.
tft_pcb_center_y = 7;
screen_center_offset_y = 0;
screen_window_y = tft_pcb_center_y + screen_center_offset_y;

// ---------- Measured ESP32 and cable bundle ----------
esp_w = 20.5;
esp_h = 52;
esp_t = 1.6;
esp_side_clearance = 0.6;
dupont_wire_length = 80;
connected_stack_depth = 23;
wire_bend_allowance = 7;

usb_connector_w = 9;
usb_connector_protrusion = 2;
usb_cutout_clearance = 0.4;
usb_cutout_w = usb_connector_w + 2 * usb_cutout_clearance; // 9.8
usb_cutout_h = 5.2;

// ---------- Enclosure ----------
case_w = 50;
case_h = 78;
rear_usb_center_y = -case_h/2 + 10; // rear-panel port, 10 mm above case bottom
corner_r = 4;
wall = 2.4;
front_plate_t = 2.6;
back_plate_t = 2.2;
internal_depth = connected_stack_depth + wire_bend_allowance; // 30
rear_tub_depth = internal_depth + back_plate_t;               // 32.2
assembled_external_depth = front_plate_t + rear_tub_depth;    // 34.8

fit_clearance = 1;
lip_h = 3;
lip_wall = 1.4;                       // safely above the printer's >1.2 mm rule
lip_tip_inset = 0.5;                  // tapered lead-in for self-alignment

// TFT mounts from the rear into blind front bosses.
tft_standoff_h = screen_above_pcb; // 2.4
tft_boss_od = 5.5;
tft_pilot_d = 1.7;
tft_pilot_depth = 1.8;

// Four M2 rear screws pass through hollow rear guides and enter short bosses
// on the front bezel.  This avoids four long front posts jamming during close.
case_screw_d = 2.25;
case_pilot_d = 1.7;
case_boss_od = 5;
case_boss_tip_d = 4.2;
case_screw_x = 10;
case_screw_y = 29;
front_case_boss_straight_h = 5;
front_case_boss_tip_h = 1;
front_case_boss_h = front_case_boss_straight_h + front_case_boss_tip_h;
rear_funnel_outer_d = 7.4;
rear_funnel_mouth_d = 5.6;
rear_funnel_throat_d = 4.6;
rear_funnel_depth = 1.2;
rear_funnel_taper_h = 1.5;
case_pilot_depth = 4;

// ESP tray on the inside of the translucent rear panel.
esp_center_y = -7;
esp_rail_w = 2;
esp_rail_projection = 3.6;
esp_rail_clearance = 0.5;
esp_bottom_stop_h = 2;
esp_stop_overlap = 0.4;              // solid overlap avoids edge-only non-manifold joins
cable_guide_d = 3.5;
cable_guide_projection = 3.2;

// Stand: a true 15-degree docking cradle, not just a decorative wedge.
stand_angle = 15;
stand_w = case_w + 10;
stand_depth = 60;
stand_base_t = 3;
stand_back_h = 32;
stand_front_lip_h = 11;
stand_support_t = 3.2;
stand_side_h = 16;
stand_side_t = 3;
stand_slot_clearance = 0.6;
stand_cable_channel_w = 14;


module rounded_rect_2d(w, h, r) {
    hull() {
        for (x = [-w/2+r, w/2-r], y = [-h/2+r, h/2-r])
            translate([x, y]) circle(r=r);
    }
}

module rounded_box(w, h, d, r) {
    linear_extrude(height=d) rounded_rect_2d(w, h, r);
}

module rounded_slot_2d(length, width) {
    hull() {
        translate([-length/2 + width/2, 0]) circle(d=width);
        translate([ length/2 - width/2, 0]) circle(d=width);
    }
}

function yz_add(a, b) = [a[0] + b[0], a[1] + b[1]];
function yz_scale(a, s) = [a[0] * s, a[1] * s];

// Extrude a polygon described in desktop-stand Y/Z coordinates along X.
module yz_extrude(points, width, x_center=0) {
    translate([x_center, 0, 0])
        rotate([0, 90, 0])
            linear_extrude(height=width, center=true, convexity=10)
                polygon(points=[for (p = points) [-p[1], p[0]]]);
}

module tft_hole_positions() {
    for (x = [-tft_hole_pitch_x/2, tft_hole_pitch_x/2],
         y = [-tft_hole_pitch_y/2, tft_hole_pitch_y/2])
        translate([x, y + tft_pcb_center_y, 0]) children();
}

module case_screw_positions() {
    for (x = [-case_screw_x, case_screw_x],
         y = [-case_screw_y, case_screw_y])
        translate([x, y, 0]) children();
}

module front_alignment_lip() {
    lip_outer_w = case_w - 2*wall - 2*fit_clearance;
    lip_outer_h = case_h - 2*wall - 2*fit_clearance;
    lip_tip_w = lip_outer_w - 2*lip_tip_inset;
    lip_tip_h = lip_outer_h - 2*lip_tip_inset;
    lip_inner_w = lip_outer_w - 2*lip_wall;
    lip_inner_h = lip_outer_h - 2*lip_wall;
    lip_inner_tip_w = lip_tip_w - 2*lip_wall;
    lip_inner_tip_h = lip_tip_h - 2*lip_wall;
    difference() {
        linear_extrude(height=lip_h,
                       scale=[lip_tip_w/lip_outer_w,
                              lip_tip_h/lip_outer_h])
            rounded_rect_2d(lip_outer_w,
                            lip_outer_h,
                            max(1, corner_r-wall));
        translate([0, 0, -0.1])
            linear_extrude(height=lip_h+0.2,
                           scale=[lip_inner_tip_w/lip_inner_w,
                                  lip_inner_tip_h/lip_inner_h])
                rounded_rect_2d(lip_inner_w,
                                lip_inner_h,
                                max(0.8, corner_r-wall-lip_wall));
    }
}

module front_bezel() {
    difference() {
        union() {
            // Visible matte-black face.
            rounded_box(case_w, case_h, front_plate_t, corner_r);

            // Shallow registration lip inside the smoke rear tub.
            translate([0, 0, front_plate_t]) front_alignment_lip();

            // TFT bosses support the PCB front surface 2.4 mm behind the screen face.
            tft_hole_positions()
                translate([0, 0, front_plate_t])
                    cylinder(d=tft_boss_od, h=tft_standoff_h);

            // Short, tapered bosses cannot bind against the rear-shell walls.
            case_screw_positions()
                translate([0, 0, front_plate_t])
                    union() {
                        cylinder(d=case_boss_od,
                                 h=front_case_boss_straight_h);
                        translate([0, 0, front_case_boss_straight_h])
                            cylinder(d1=case_boss_od,
                                     d2=case_boss_tip_d,
                                     h=front_case_boss_tip_h);
                    }
        }

        // Screen window; leaves about 0.2 mm of the 1 mm black border visible.
        translate([-screen_window_w/2,
                   -screen_window_h/2 + screen_window_y,
                   -0.5])
            cube([screen_window_w, screen_window_h, front_plate_t + 1]);

        // Blind TFT pilot holes, open only from the rear of each boss.
        tft_hole_positions()
            translate([0, 0,
                       front_plate_t + tft_standoff_h - tft_pilot_depth])
                cylinder(d=tft_pilot_d, h=tft_pilot_depth + 0.5);

        // Blind case-post pilot holes for M2 screws entering from the rear.
        case_screw_positions()
            translate([0, 0,
                       front_plate_t + front_case_boss_h - case_pilot_depth])
                cylinder(d=case_pilot_d, h=case_pilot_depth + 0.5);
    }
}

module vent_slots() {
    for (y = [14, 19, 24])
        translate([0, y, internal_depth - 0.5])
            linear_extrude(height=back_plate_t + 1)
                rounded_slot_2d(18, 2.2);
}

module esp_tray_and_guides() {
    // Rear interior face is z=internal_depth. Rails project forward (toward z=0).
    rail_z = internal_depth - esp_rail_projection;
    rail_y0 = esp_center_y - esp_h/2;

    // Two side guides; deliberately loose for FDM tolerance.
    for (x = [-esp_w/2 - esp_side_clearance - esp_rail_w,
               esp_w/2 + esp_side_clearance])
        translate([x, rail_y0-esp_stop_overlap, rail_z])
            cube([esp_rail_w,
                  esp_h+esp_stop_overlap,
                  esp_rail_projection]);

    // Extend through both rails and overlap them in Y. The previous version
    // only touched each rail along one vertical edge, creating two bad edges.
    // The board-facing stop plane remains at rail_y0, so usable space is unchanged.
    translate([-esp_w/2-esp_side_clearance-esp_rail_w,
               rail_y0-esp_bottom_stop_h,
               rail_z])
        cube([esp_w+2*esp_side_clearance+2*esp_rail_w,
              esp_bottom_stop_h,
              esp_rail_projection]);
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

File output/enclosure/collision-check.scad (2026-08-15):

part = "collision";
include <codex_widget_enclosure.scad>;

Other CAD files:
output/enclosure/back-smoke-petg-v6-wide.stl
output/enclosure/back-smoke-petg.stl
output/enclosure/back-smoke-petg-v2-rear-usbc.stl
output/enclosure/back-smoke-petg-v4-self-align.stl
output/enclosure/front-black.scad
output/enclosure/full-assembly-collision-check.scad
output/enclosure/stand-assembly-preview.scad
output/enclosure/stand-black.scad
output/enclosure/stand-fit-preview.scad

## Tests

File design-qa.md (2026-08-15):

# Design QA — Combined 3D Manipulator

## Target

- Reference static state: `/var/folders/jh/pjjtryy945q7q_1xvnmvht500000gn/T/codex-clipboard-ca2cef84-b3d6-4a42-ac67-5887cbf78353.png`
- Reference rotation state: `/var/folders/jh/pjjtryy945q7q_1xvnmvht500000gn/T/codex-clipboard-fbc0f48c-85e6-4662-8c49-2512e25dec4e.png`
- Implementation static state: `.playwright-cli/page-2026-08-15T08-27-40-402Z.png`
- Implementation rotation state: `.playwright-cli/page-2026-08-15T08-28-01-030Z.png`
- Side-by-side comparison: `.playwright-cli/design-comparison.png`
- Desktop viewport: `1440 × 980`; implementation viewport crop: `1140 × 770` at `(300, 120)`.
- Mobile viewport: `390 × 844`; 3D viewport: `390 × 648`.

## Visual comparison

- Static selection state matches the reference interaction hierarchy: cyan selected outline, eight square scale handles, a dashed vertical lift control, and external rotation affordances shown at the same time.
- Active rotation state matches the reference's two-zone dial: a 16-segment fixed inner ring and a separate outer fine-control band.
- The live angle readout is positioned at the active pointer and reproduced the reference value `-4°`; the implementation adds the useful precision label `精细 1°`.
- Axis-specific rotation handles are color-coded and labeled X/Y/Z so all three rotation planes are discoverable without switching tools.
- The implementation keeps Print Lab's existing orange/cyan product palette instead of copying Tinkercad's purple model material.
- Handles clamp to the visible viewport edge when the projected model bounds exceed the camera crop. At `390 × 844`, every scale, rotation, and lift handle remained inside the interactive viewport with no horizontal document overflow.

## Functional checks

- Direct model-body drag changed X/Y position from `0.0, 0.0` to `2.8, -8.4`.
- East scale handle changed X scale from `1.00` to `1.26` and showed `X 1.26×`.
- Lift handle changed Z from `0.0` to `10.0 mm`.
- Inner rotation ring produced `90.0°`, an exact `22.5°` increment, with `固定 22.5°` feedback.
- Outer rotation ring produced `112°` and `-4°` with `精细 1°` feedback.
- Browser console: 0 errors, 0 warnings. Failed application requests: 0.
- X/Y rotation performance pass: pointer updates are coalesced to animation frames, the rotation dial remains fixed during drag, inspector/stat recomputation is deferred until pointer-up, and Retina rendering temporarily drops to 1× only while dragging before restoring full resolution.
- X and Y regression drag each completed at `90.0°` with matching live readouts and a stable dial center.
- Generic physics pass: Rapier loads only when requested; selected-only and all-part free fall use dynamic convex-hull colliders, static triangle-mesh colliders, a fixed print-bed collider, CCD, friction, restitution, pause/resume, collision counting, and position restore.
- Two-part all-body regression produced `碰撞 2`; manual transforms were locked during simulation, the gizmo was hidden, and reset restored the editing state.
- Manual collision regression with `front-black-v5-wide.stl` and `back-smoke-petg-v6-wide.stl`: moving the second part from X `62.0` toward X `0.0` stopped at the last safe pose, X `50.4`, instead of overlapping. The same path guard is used by direct body drag, lift, rotation, centering, bed placement, numeric position, and numeric rotation.
- Near-contact performance regression: an isolated 80-event pointer-handler run held against the other part completed in `199.3 ms` total (`2.49 ms/event` average); the steady-state SAT checks were normally `0–0.2 ms`. Live editing now uses Three.js's existing 3D OBB/SAT implementation with cached local OBBs. Rapier is lazy-loaded only for free-fall and low-frequency large transforms that need native collider casting/CCD.
- Contact-release regression with two generic `40 × 40 × 20 mm` boxes: the moving box stopped at the separating boundary, then moved away and returned to the cyan selection outline during the same uninterrupted pointer gesture. The 15-point collide-and-reverse browser drag completed in `35 ms`; no deselection or second click was required.
- Pointer-follow regression with two generic `40 × 40 × 20 mm` parts: one sparse two-point drag moved the selected part directly from `X 52.0, Y 0.0` to `X 138.8, Y 15.6` in `49 ms`, rather than advancing only the former `2.5 mm` per-event cap. A separate two-point drag aimed through the other part still stopped at the separating boundary (`X 9.7, Y -2.3` versus the obstacle at `X 52.0, Y 0.0`) in `27 ms`.
- Post-contact continuity regression: one uninterrupted drag moved into the other generic part and then reversed through 24 consecutive `5 px` pointer increments. Every reverse increment stayed in contact-relative mode, the part finished separated at `X 59.3, Y -14.2`, the outline was cyan, and the full path completed in `60 ms` without reselecting or releasing the pointer.
- All-body thin-platform regression: a generic `100 × 100 × 2 mm` dynamic plate and two centered dynamic boxes (`20 mm` and `16 mm` tall) were spawned in non-overlapping vertical intervals. After settling, their root Z positions were exactly `0.0`, `2.0`, and `22.0 mm`, proving both boxes rested on the preceding collider instead of tunnelling through the plate. Rapier reported 5 contacts; browser console had 0 errors and 0 warnings.
- Selection flicker regression: both a parts-list switch and a direct canvas click changed the selected part while the WebGL canvas PNG remained byte-for-byte identical (`27,718` data-URL characters before and after). Selection now updates only the 2D overlay and DOM inspector; an un-dragged click does not change renderer pixel ratio or call WebGL render.
- `npm run viewer:build`: passed.
- `npm test`: 5 passed, 0 failed.

## Iteration history

1. Replaced three mutually exclusive move/rotate/scale modes and Three.js TransformControls with one persistent combined manipulator.
2. Added viewport projection, handle hit-testing, pointer capture, real-time numeric feedback, fixed/fine rotation modes, direct model drag preservation, and mobile-safe handle clamping.
3. Compared both reference states and both implementation states in one composite image, then verified the reference's key visual and behavioral traits were present.
4. Removed idle geometry recomputation and the per-pointer X/Y bounding-box/statistics work after hands-on feedback about rotation stutter.
5. Added lazy-loaded generic rigid-body physics and replaced destructive selection rerenders with in-place list updates.
6. Added default-on edit collision protection, removed the WebGL selection helper, and delayed drag-quality switching until the pointer crosses the movement threshold.
7. Replaced per-pointer physics stepping with the existing Three.js OBB/SAT narrow phase, cached local OBBs at import time, moved collision feedback onto the gizmo canvas, and kept Rapier's native collider cast/CCD for large one-shot transforms and rigid-body simulation.
8. Fixed contact release by comparing adjacent pointer targets instead of the stale absolute target: inward input is rejected, tangent input slides along the contact, and outward input immediately resumes from the last accepted pose.
9. Removed the `2.5 mm` accepted-movement cap that made fast drags lag behind the pointer. Live edits now subdivide the full requested path for cached OBB/SAT checks and accept the complete pointer pose whenever every sample is clear.
10. Kept pointer movement in incremental contact-relative mode for the remainder of a drag after its first collision. This prevents the next frame from jumping back to the stale, penetrating absolute target and eliminates alternating red-frame stalls while dragging away.
11. Made free-fall initialization collision-safe: dynamic bodies now start in disjoint vertical intervals, Rapier runs four hard-CCD substeps plus soft CCD and extra solver iterations, and degenerate per-mesh convex hulls receive a conservative thin-box fallback instead of leaving holes in compound parts.

final result: passed

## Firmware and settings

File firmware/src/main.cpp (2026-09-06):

#include <Arduino.h>
#include <ArduinoJson.h>
#include <HTTPClient.h>
#include <TFT_eSPI.h>
#include <U8g2_for_TFT_eSPI.h>
#include <WiFi.h>
#include <time.h>
#include <freertos/FreeRTOS.h>
#include <freertos/queue.h>
#include <freertos/task.h>

#include "flip_clock.h"

#include "config_portal.h"
#include "ble_thermometer.h"
#include "device_config.h"

namespace {
constexpr uint16_t kBackground = TFT_BLACK;
constexpr uint16_t kPanel = 0x1082;
constexpr uint16_t kMuted = 0x8C71;
constexpr uint16_t kGreen = 0x3F67;
constexpr uint16_t kAmber = 0xFD20;
constexpr uint16_t kRed = 0xF986;
constexpr uint16_t kGraffitiBackground = 0x0841;
constexpr uint16_t kGraffitiPanel = 0x10A2;
constexpr uint16_t kGraffitiPanelEdge = 0x4208;
constexpr uint16_t kGraffitiTexture = 0x2104;
constexpr uint16_t kGraffitiOutline = 0xD69A;
constexpr uint16_t kGraffitiPink = 0xF9B0;
constexpr uint16_t kGraffitiGreen = 0xA7E0;
constexpr unsigned long kWifiConnectTimeoutMs = 15000;
constexpr unsigned long kNoDataClockTimeoutMs = 30000;
constexpr time_t kMinimumValidEpoch = 1609459200;  // 2021-01-01 UTC
constexpr int kIdleCardX[] = {4, 84, 164};
constexpr int kIdleCardY = 30;
constexpr int kIdleCardWidth = 72;
constexpr int kIdleCardHeight = 152;
constexpr int kIdleCardHalf = kIdleCardHeight / 2;

enum class DisplayMode {
  kUnknown,
  kStatus,
  kIdleClock,
  kOffline,
};

TFT_eSPI tft;
U8g2_for_TFT_eSPI utf8Font;
WidgetConfig widgetConfig;
unsigned long lastPollAt = 0;
unsigned long lastClockDrawAt = 0;
unsigned long lastResetDrawAt = 0;
unsigned long lastFreshStatusAt = 0;
unsigned long configButtonPressedAt = 0;
bool hasRenderedStatus = false;
bool bridgeHealthy = false;
int64_t weeklyResetsAt = 0;
DisplayMode displayMode = DisplayMode::kUnknown;
int lastIdleHour = -1;
int lastIdleMinute = -1;
int lastIdleSecond = -1;
TFT_eSprite clockOld(&tft);
TFT_eSprite clockNext(&tft);
TFT_eSprite clockFrame(&tft);
bool clockBuffersReady = false;
bool clockFlipActive = false;
bool clockChanged[3] = {};
unsigned long clockFlipStartedAt = 0;
unsigned long clockFrameAt = 0;
bool idleClockSceneDrawn = false;

struct StatusResult {
  JsonDocument document;
  String error;
};
QueueHandle_t statusResults = nullptr;
TaskHandle_t statusWorker = nullptr;
bool statusRequestPending = false;

uint16_t quotaColor(float usedPercent) {
  if (usedPercent >= 90) return kRed;
  if (usedPercent >= 70) return kAmber;
  return kGreen;
}

String timeUntil(int64_t epochSeconds) {
  if (epochSeconds <= 0) return "--";
  const time_t now = time(nullptr);
  if (now < kMinimumValidEpoch) return "--";
  const int64_t seconds = epochSeconds - now;
  if (seconds <= 0) return "now";
  const int days = seconds / 86400;
  const int hours = (seconds % 86400) / 3600;
  if (days > 0) return String(days) + "d " + String(hours) + "h";
  const int minutes = (seconds % 3600) / 60;
  return String(hours) + "h " + String(minutes) + "m";
}

void drawResetCountdown() {
  // Clear only the countdown value so it can update independently after NTP sync.
  tft.fillRect(68, 89, 70, 24, kBackground);
  tft.setTextDatum(TL_DATUM);
  tft.setTextColor(TFT_WHITE, kBackground);
  tft.drawString(timeUntil(weeklyResetsAt), 69, 92, 2);
}

String fitText(String text, size_t maxLength) {
  text.replace("\n", " ");
  text.trim();
  if (text.length() <= maxLength) return text;
  return text.substring(0, maxLength - 3) + "...";
}

String fitUtf8Text(String text, int maxWidth) {
  text.replace("\n", " ");
  text.trim();
  if (utf8Font.getUTF8Width(text.c_str()) <= maxWidth) return text;

  int end = text.length();
  while (end > 0) {
    int previous = end - 1;
    while (previous > 0 && (static_cast<uint8_t>(text[previous]) & 0xC0) == 0x80) {
      previous--;
    }
    end = previous;
    const String candidate = text.substring(0, end) + "...";
    if (utf8Font.getUTF8Width(candidate.c_str()) <= maxWidth) return candidate;
  }
  return "...";
}

String clockText() {
  struct tm localTime;
  if (!getLocalTime(&localTime, 10)) return "--:--";
  char buffer[6];
  strftime(buffer, sizeof(buffer), "%H:%M", &localTime);
  return String(buffer);
}

bool localClock(int &hour, int &minute, int &second) {
  const time_t now = time(nullptr);
  if (now < kMinimumValidEpoch) return false;
  struct tm localTime;
  localtime_r(&now, &localTime);
  hour = localTime.tm_hour;
  minute = localTime.tm_min;
  second = localTime.tm_sec;
  return true;
}

bool ensureClockBuffers() {
  if (clockBuffersReady) return true;
  clockBuffersReady = clockOld.createSprite(kIdleCardWidth * 3, kIdleCardHeight) &&
                      clockNext.createSprite(kIdleCardWidth * 3, kIdleCardHeight) &&
                      clockFrame.createSprite(kIdleCardWidth, kIdleCardHeight);
  if (!clockBuffersReady) {
    clockOld.deleteSprite();
    clockNext.deleteSprite();
    clockFrame.deleteSprite();
  }
  Serial.printf("[clock] HH:MM:SS flip buffers %s, duration %lums\n",
                clockBuffersReady ? "ready" : "unavailable (static fallback)",
                flip_clock::kDurationMs);
  return clockBuffersReady;
}

template <typename Canvas>
void drawPaintSegment(Canvas &canvas, int x, int y, int width, int height,
                      uint16_t color) {
  canvas.fillRoundRect(x - 1, y - 1, width + 2, height + 2, 3, kGraffitiOutline);
  canvas.fillRoundRect(x, y, width, height, 2, color);
}

template <typename Canvas>
void drawGraffitiDigit(Canvas &canvas, int x, int y, int digit, uint16_t color) {
  constexpr uint8_t segments[] = {0x3f, 0x06, 0x5b, 0x4f, 0x66,
                                  0x6d, 0x7d, 0x07, 0x7f, 0x6f};
  if (digit == 1) {
    drawPaintSegment(canvas, x + 11, y + 2, 7, 98, color);
    drawPaintSegment(canvas, x + 5, y + 7, 13, 6, color);
    drawPaintSegment(canvas, x + 5, y + 96, 20, 6, color);
  } else {
    const uint8_t mask = digit < 0 ? 0x40 : segments[digit];
    if (mask & 0x01) drawPaintSegment(canvas, x + 4, y, 20, 7, color);
    if (mask & 0x02) drawPaintSegment(canvas, x + 21, y + 5, 6, 43, color);
    if (mask & 0x04) drawPaintSegment(canvas, x + 21, y + 55, 6, 43, color);
    if (mask & 0x08) drawPaintSegment(canvas, x + 4, y + 96, 20, 7, color);
    if (mask & 0x10) drawPaintSegment(canvas, x + 1, y + 55, 6, 43, color);
    if (mask & 0x20) drawPaintSegment(canvas, x + 1, y + 5, 6, 43, color);
    if (mask & 0x40) drawPaintSegment(canvas, x + 4, y + 48, 20, 7, color);
  }
  for (int mark = 0; mark < 12; ++mark) {
    canvas.drawFastHLine(x + 3 + (mark * 17 + max(0, digit) * 3) % 22,
                         y + 3 + (mark * 29) % 98, 2, kGraffitiPanel);
  }
  if (digit >= 0) {
    for (int drip = 0; drip < 2; ++drip) {
      const int px = x + 5 + (digit * 3 + drip * 11) % 19;
      canvas.drawFastVLine(px, y + 105, 4 + (digit + drip * 3) % 9, color);
    }
  }
}

template <typename Canvas>
void drawGraffitiCard(Canvas &canvas, int x, int y, int group, int value) {
  canvas.fillRect(x, y, kIdleCardWidth, kIdleCardHeight, kGraffitiBackground);
  canvas.fillRoundRect(x, y, kIdleCardWidth, kIdleCardHeight, 5, kGraffitiPanel);
  canvas.drawRoundRect(x, y, kIdleCardWidth, kIdleCardHeight, 5, kGraffitiPanelEdge);
  for (int mark = 0; mark < 24; ++mark) {
    canvas.drawPixel(x + 3 + (mark * 19 + group * 7) % 65,
                     y + 3 + (mark * 37) % 145, kGraffitiTexture);
  }
  const uint16_t color = group == 1 ? kGraffitiGreen : kGraffitiPink;
  drawGraffitiDigit(canvas, x + 5, y + 24, value < 0 ? -1 : value / 10, color);
  drawGraffitiDigit(canvas, x + 39, y + 24, value < 0 ? -1 : value % 10, color);
  canvas.drawFastHLine(x + 2, y + kIdleCardHalf - 1, kIdleCardWidth - 4, TFT_BLACK);
  canvas.drawFastHLine(x + 2, y + kIdleCardHalf, kIdleCardWidth - 4, TFT_BLACK);
  canvas.drawFastHLine(x + 5, y + kIdleCardHalf + 1, kIdleCardWidth - 10,
                       kGraffitiPanelEdge);
  canvas.fillCircle(x + 2, y + kIdleCardHalf, 2, kGraffitiOutline);
  canvas.fillCircle(x + kIdleCardWidth - 3, y + kIdleCardHalf, 2, kGraffitiOutline);
}

void drawGraffitiColon() {
  for (int x : {80, 160}) {
    tft.fillCircle(x, 92, 2, kGraffitiOutline);
    tft.fillCircle(x, 120, 2, kGraffitiOutline);
  }
}

// Sprite pixels are stored byte-swapped by TFT_eSPI. Compose the entire card
// offscreen, including the stationary halves, and transfer it once per frame.
void drawClockFlipFrame(unsigned long elapsed) {
  const flip_clock::Frame motion = flip_clock::frame(elapsed, kIdleCardHalf);
  auto *oldPixels = static_cast<uint16_t *>(clockOld.getPointer());
  auto *nextPixels = static_cast<uint16_t *>(clockNext.getPointer());
  auto *pixels = static_cast<uint16_t *>(clockFrame.getPointer());
  constexpr int stride = kIdleCardWidth * 3;
  for (int group = 0; group < 3; ++group) {
    if (!clockChanged[group]) continue;
    for (int y = 0; y < kIdleCardHeight; ++y) {
      const auto row = flip_clock::row(motion, y, kIdleCardHalf);
      const auto *source = row.oldPage ? oldPixels : nextPixels;
      for (int x = 0; x < kIdleCardWidth; ++x) {
        uint16_t pixel = source[row.sourceY * stride + group * kIdleCardWidth + x];
        if (row.moving) pixel = flip_clock::shadeSwapped565(pixel, motion.light);
        pixels[y * kIdleCardWidth + x] = pixel;
      }
    }
    // The leading edge travels toward / away from the hinge, following the
    // projected digit itself instead of covering it with an opaque band.
    if (motion.height > 0 && elapsed < flip_clock::kDurationMs) {
      const int edge = motion.falling ? kIdleCardHalf + motion.height - 1
                                      : kIdleCardHalf - motion.height;
      clockFrame.drawFastHLine(3, edge, kIdleCardWidth - 6, kGraffitiOutline);
    }
    clockFrame.drawFastHLine(2, kIdleCardHalf - 1, kIdleCardWidth - 4, TFT_BLACK);
    clockFrame.drawFastHLine(2, kIdleCardHalf, kIdleCardWidth - 4, TFT_BLACK);
    clockFrame.fillCircle(2, kIdleCardHalf, 2, kGraffitiOutline);
    clockFrame.fillCircle(kIdleCardWidth - 3, kIdleCardHalf, 2, kGraffitiOutline);
    clockFrame.pushSprite(kIdleCardX[group], kIdleCardY);
  }
}

void drawIdleClockFooter() {
  tft.fillRect(0, 202, 240, 38, kGraffitiBackground);
  tft.drawFastHLine(12, 207, 216, kGraffitiTexture);

  const BleThermometerReading thermometer = getBleThermometerReading();
  String environment = "ROOM --";
  if (thermometer.hasValue) {
    environment = String(thermometer.temperatureC, 1) + "C " +
                  String(thermometer.humidityPercent) + "%";
  } else if (thermometer.state == BleThermometerState::kScanning ||
             thermometer.state == BleThermometerState::kConnecting) {
    environment = "ROOM ...";
  }

  tft.setTextDatum(TL_DATUM);
  tft.setTextColor(kGraffitiPanelEdge, kGraffitiBackground);
  tft.drawString(bridgeHealthy ? "IDLE" : "CLOCK", 12, 218, 2);
  tft.setTextColor(kGraffitiOutline, kGraffitiBackground);
  tft.drawString(environment, 55, 218, 2);
  tft.fillCircle(188, 226, 3, bridgeHealthy ? kGreen : kAmber);
  tft.setTextDatum(TR_DATUM);
  tft.drawString(bridgeHealthy ? "LIVE" : "STALE", 228, 218, 2);
  tft.setTextDatum(TL_DATUM);
}

void drawIdleClockScene(int hour, int minute, int second) {
  tft.fillScreen(kGraffitiBackground);
  const int values[] = {hour, minute, second};
  const char *labels[] = {"HOUR", "MIN", "SEC"};
  tft.setTextDatum(TC_DATUM);
  tft.setTextColor(kGraffitiOutline, kGraffitiBackground);
  for (int group = 0; group < 3; ++group) {
    drawGraffitiCard(tft, kIdleCardX[group], kIdleCardY, group, values[group]);
    tft.drawString(labels[group], kIdleCardX[group] + kIdleCardWidth / 2, 9, 2);
  }
  drawGraffitiColon();
  drawIdleClockFooter();
}

void updateIdleClock(bool forceRedraw) {
  int hour = -1, minute = -1, second = -1;
  const bool hasTime = localClock(hour, minute, second);
  if (forceRedraw || !idleClockSceneDrawn) {
    clockFlipActive = false;
    ensureClockBuffers();
    drawIdleClockScene(hour, minute, second);
    idleClockSceneDrawn = true;
  } else if (hasTime && (hour != lastIdleHour || minute != lastIdleMinute ||
                         second != lastIdleSecond)) {
    if (clockFlipActive) drawClockFlipFrame(flip_clock::kDurationMs);
    const int previous[] = {lastIdleHour, lastIdleMinute, lastIdleSecond};
    const int next[] = {hour, minute, second};
    // First sync and time corrections snap to the actual time. Never replay
    // stale seconds after an outage or continue an animation from old buffers.
    clockFlipActive = clockBuffersReady &&
        flip_clock::isNextSecond(lastIdleHour, lastIdleMinute, lastIdleSecond,
                                 hour, minute, second);
    for (int group = 0; group < 3; ++group) {
      clockChanged[group] = previous[group] != next[group];
      if (!clockChanged[group]) continue;
      if (clockFlipActive) {
        drawGraffitiCard(clockOld, group * kIdleCardWidth, 0, group, previous[group]);
        drawGraffitiCard(clockNext, group * kIdleCardWidth, 0, group, next[group]);
      } else {
        drawGraffitiCard(tft, kIdleCardX[group], kIdleCardY, group, next[group]);
      }
    }
    clockFlipStartedAt = millis();
    clockFrameAt = millis() - 25;
  }
  if (hasTime) {
    lastIdleHour = hour;
    lastIdleMinute = minute;
    lastIdleSecond = second;
  }
  if (clockFlipActive && millis() - clockFrameAt >= 25) {
    clockFrameAt = millis();
    const unsigned long elapsed = millis() - clockFlipStartedAt;
    drawClockFlipFrame(elapsed);
    if (elapsed >= flip_clock::kDurationMs) clockFlipActive = false;
  }
}

void showIdleClock() {
  if (displayMode != DisplayMode::kIdleClock) {
    displayMode = DisplayMode::kIdleClock;
    lastIdleHour = -1;
    lastIdleMinute = -1;
    lastIdleSecond = -1;
    idleClockSceneDrawn = false;
    Serial.println(bridgeHealthy ? "[display] idle clock" : "[display] offline clock");
    updateIdleClock(true);
  } else {
    drawIdleClockFooter();
  }
}

void updateNoDataTimeout() {
  // Use a monotonic timer: NTP corrections must not affect the fallback.
  // A configured 60-second poll interval is not itself a connection failure.
  if (!bridgeHealthy && millis() - lastFreshStatusAt >= kNoDataClockTimeoutMs) {
    if (displayMode != DisplayMode::kIdleClock) showIdleClock();
  }
}

void drawHeader(bool online) {
  tft.fillRect(0, 0, 240, 35, kBackground);
  tft.setTextDatum(TL_DATUM);
  tft.setTextColor(TFT_WHITE, kBackground);
  tft.drawString("CODEX", 12, 9, 4);
  tft.fillCircle(171, 17, 4, online ? kGreen : kAmber);
  tft.setTextDatum(TR_DATUM);
  tft.setTextColor(TFT_WHITE, kBackground);
  tft.drawString(clockText(), 228, 10, 2);
  tft.setTextDatum(TL_DATUM);
}

void drawFooter() {
  tft.fillRect(0, 216, 240, 24, kBackground);
  const bool wifiConnected = WiFi.status() == WL_CONNECTED;
  tft.fillCircle(12, 228, 3, wifiConnected ? kGreen : kRed);
  tft.setTextColor(kMuted, kBackground);
  const String wifiText = wifiConnected ? String(WiFi.RSSI()) + "dB" : "OFF";
  tft.drawString(wifiText, 20, 220, 2);

  const BleThermometerReading thermometer = getBleThermometerReading();
  String thermometerText;
  uint16_t thermometerColor = kMuted;
  if (thermometer.hasValue) {
    thermometerText = String(thermometer.temperatureC, 1) + "C " +
                      String(thermometer.humidityPercent) + "%";
    const bool fresh = millis() - thermometer.updatedAtMs <= 180000;
    thermometerColor = fresh ? TFT_WHITE : kAmber;
  } else if (thermometer.state == BleThermometerState::kScanning ||
             thermometer.state == BleThermometerState::kConnecting) {
    thermometerText = "BLE...";
  } else if (thermometer.state == BleThermometerState::kReadError) {
    thermometerText = "BLE ERR";
    thermometerColor = kAmber;
  } else {
    thermometerText = "BLE --";
  }
  tft.setTextDatum(TC_DATUM);
  tft.setTextColor(thermometerColor, kBackground);
  tft.drawString(thermometerText, 132, 220, 2);

  tft.setTextDatum(TR_DATUM);
  tft.setTextColor(bridgeHealthy ? kGreen : kAmber, kBackground);
  tft.drawString(bridgeHealthy ? "LIVE" : "STALE", 228, 220, 2);
  tft.setTextDatum(TL_DATUM);
}

void drawProgressBar(int x, int y, int width, float usedPercent) {
  tft.fillRoundRect(x, y, width, 11, 5, 0x2945);
  const int filled = max(0, min(width, static_cast<int>(width * usedPercent / 100.0f)));
  if (filled > 0) tft.fillRoundRect(x, y, filled, 11, 5, quotaColor(usedPercent));
}

void drawOffline(const String &message) {
  displayMode = DisplayMode::kOffline;
  drawHeader(false);
  tft.fillRect(0, 35, 240, 205, kBackground);
  tft.setTextColor(TFT_WHITE, kBackground);
  tft.drawCentreString("NO DATA", 120, 85, 4);
  tft.setTextColor(kMuted, kBackground);
  tft.drawCentreString(fitText(message, 30), 120, 125, 2);
  drawFooter();
}

void drawStatus(JsonDocument &doc) {
  const float weeklyUsed = doc["quota"]["weekly"]["usedPercent"] | 0.0f;
  weeklyResetsAt = doc["quota"]["weekly"]["resetsAt"] | 0LL;
  const int resetCredits = doc["resetCredits"] | -1;
  const int runningCount = doc["runningCount"] | 0;

  bridgeHealthy = true;
  lastFreshStatusAt = millis();
  hasRenderedStatus = true;

  if (runningCount == 0) {
    showIdleClock();
    return;
  }

  if (displayMode != DisplayMode::kStatus) Serial.println("[display] live status");
  displayMode = DisplayMode::kStatus;
  drawHeader(bridgeHealthy);
  tft.fillRect(0, 35, 240, 181, kBackground);

  tft.setTextColor(kMuted, kBackground);
  tft.drawString("WEEKLY", 12, 45, 2);
  tft.setTextDatum(TR_DATUM);
  tft.setTextColor(TFT_WHITE, kBackground);
  tft.drawString(String(static_cast<int>(roundf(weeklyUsed))) + "%", 228, 41, 4);
  tft.setTextDatum(TL_DATUM);
  drawProgressBar(12, 72, 216, weeklyUsed);

  tft.setTextColor(kMuted, kBackground);
  tft.drawString("RESET", 12, 93, 2);
  drawResetCountdown();
  tft.setTextColor(kMuted, kBackground);
  tft.drawString("CREDITS", 143, 93, 2);
  tft.setTextDatum(TR_DATUM);
  tft.setTextColor(TFT_WHITE, kBackground);
  tft.drawString(resetCredits < 0 ? "--" : String(resetCredits), 228, 92, 2);
  tft.setTextDatum(TL_DATUM);

  tft.drawFastHLine(12, 119, 216, 0x3186);
  tft.fillCircle(17, 139, 4, runningCount > 0 ? kGreen : kMuted);
  tft.setTextColor(TFT_WHITE, kBackground);
  tft.drawString("RUNNING", 29, 132, 2);
  tft.setTextDatum(TR_DATUM);
  tft.drawString(String(runningCount), 228, 132, 2);
  tft.setTextDatum(TL_DATUM);

  JsonArray running = doc["running"].as<JsonArray>();
  int y = 158;
  int shown = 0;
  for (JsonObject task : running) {
    if (shown >= 2) break;
    const char *taskTitle = task["title"].as<const char *>();
    if (taskTitle == nullptr || taskTitle[0] == '\0') {
      taskTitle = task["displayName"].as<const char *>();
    }
    if (taskTitle == nullptr || taskTitle[0] == '\0') taskTitle = "未命名任务";
    Serial.printf("[task] title: %s\n", taskTitle);
    const String title = fitUtf8Text(String(shown + 1) + "  " + taskTitle, 216);
    utf8Font.setForegroundColor(shown == 0 ? TFT_WHITE : kMuted);
    utf8Font.drawUTF8(12, y + 14, title.c_str());
    y += 23;
    shown++;
  }
  if (shown == 0) {
    tft.setTextColor(kMuted, kBackground);
    tft.drawString("No active tasks", 12, 158, 2);
  }
  drawFooter();
}

void markConnectionStale(const String &reason) {
  bridgeHealthy = false;
  Serial.println("[bridge] " + reason);
  if (displayMode == DisplayMode::kIdleClock) {
    drawIdleClockFooter();
  } else if (hasRenderedStatus) {
    drawHeader(false);
    drawFooter();
  } else {
    drawOffline(reason);
  }
}

// Network I/O owns no display state. The main loop alone renders, even when
// a connection or response takes several seconds to time out.
void fetchStatusInBackground(StatusResult &result, const String &url) {
  if (WiFi.status() != WL_CONNECTED) {
    result.error = "Wi-Fi disconnected";
    return;
  }
  HTTPClient http;
  http.setConnectTimeout(4000);
  http.setTimeout(4000);
  if (!http.begin(url)) {
    result.error = "Invalid bridge URL";
    return;
  }
  const int code = http.GET();
  if (code != HTTP_CODE_OK) {
    http.end();
    result.error = "HTTP " + String(code);
    return;
  }
  const DeserializationError error = deserializeJson(result.document, http.getStream());
  http.end();
  if (error) {
    result.error = "Invalid JSON";
    return;
  }
  JsonDocument &doc = result.document;
  if (!(doc["ok"] | false) || (doc["stale"] | false)) {
    result.error = "Bridge data unavailable";
    return;
  }
  if (!doc["runningCount"].is<int>() || doc["runningCount"].as<int>() < 0) {
    result.error = "Invalid status payload";
  }
}

void statusWorkerLoop(void *) {
  // Configuration changes reboot the device; take a private immutable copy.
  const String url = widgetConfig.bridgeUrl;
  for (;;) {
    ulTaskNotifyTake(pdTRUE, portMAX_DELAY);
    auto *result = new StatusResult;
    fetchStatusInBackground(*result, url);
    xQueueSend(statusResults, &result, portMAX_DELAY);
  }
}
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
void loop() {
  handleLanConfigServer();
  handleConfigButton();
  receiveStatus();
  updateNoDataTimeout();

  const unsigned long pollIntervalMs = widgetConfig.pollIntervalSeconds * 1000UL;
  if (millis() - lastPollAt >= pollIntervalMs) {
    lastPollAt = millis();
    if (WiFi.status() != WL_CONNECTED) {
      WiFi.reconnect();
      markConnectionStale("Wi-Fi disconnected");
    } else {
      fetchStatus();
    }
  }

  updateNoDataTimeout();
  if (displayMode == DisplayMode::kIdleClock) updateIdleClock(false);
  if (millis() - lastClockDrawAt >= 1000) {
    lastClockDrawAt = millis();
    if (displayMode == DisplayMode::kIdleClock) {
      drawIdleClockFooter();
    } else if (displayMode == DisplayMode::kStatus) {
      drawHeader(bridgeHealthy);
      drawFooter();
    }
  }
  if (displayMode == DisplayMode::kStatus && hasRenderedStatus &&
      millis() - lastResetDrawAt >= 1000) {
    lastResetDrawAt = millis();
    drawResetCountdown();
  }
  delay(displayMode == DisplayMode::kIdleClock ? 5 : 50);
}

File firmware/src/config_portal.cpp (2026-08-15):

#include "config_portal.h"

#include <DNSServer.h>
#include <ESPmDNS.h>
#include <WebServer.h>
#include <WiFi.h>

namespace {
constexpr char kSetupPassword[] = "codexsetup";
constexpr char kLanHostname[] = "codex-widget";
constexpr uint16_t kDnsPort = 53;
WebServer lanWebServer(80);
bool restartPending = false;
unsigned long restartAt = 0;

String htmlEscape(const String &input) {
  String output;
  output.reserve(input.length() + 16);
  for (size_t index = 0; index < input.length(); index++) {
    switch (input[index]) {
      case '&': output += F("&amp;"); break;
      case '<': output += F("&lt;"); break;
      case '>': output += F("&gt;"); break;
      case '"': output += F("&quot;"); break;
      case '\'': output += F("&#39;"); break;
      default: output += input[index]; break;
    }
  }
  return output;
}

String setupAccessPointName() {
  const uint64_t chipId = ESP.getEfuseMac();
  char suffix[5];
  snprintf(suffix, sizeof(suffix), "%04X", static_cast<uint16_t>(chipId & 0xFFFF));
  return "Codex-Widget-" + String(suffix);
}

String timezoneOption(const char *id, const char *label, const String &selectedId) {
  String option = "<option value=\"" + String(id) + "\"";
  if (selectedId == id) option += " selected";
  option += ">" + String(label) + "</option>";
  return option;
}

String timezoneOptions(const String &selectedId) {
  String options;
  options.reserve(1200);
  options += timezoneOption("Asia/Shanghai", "中国标准时间 · 上海（UTC+8）", selectedId);
  options += timezoneOption("Asia/Singapore", "新加坡（UTC+8）", selectedId);
  options += timezoneOption("Asia/Tokyo", "日本 · 东京（UTC+9）", selectedId);
  options += timezoneOption("Asia/Kolkata", "印度 · 加尔各答（UTC+5:30）", selectedId);
  options += timezoneOption("Asia/Dubai", "阿联酋 · 迪拜（UTC+4）", selectedId);
  options += timezoneOption("Europe/London", "英国 · 伦敦", selectedId);
  options += timezoneOption("Europe/Berlin", "欧洲中部 · 柏林", selectedId);
  options += timezoneOption("America/New_York", "美国东部 · 纽约", selectedId);
  options += timezoneOption("America/Chicago", "美国中部 · 芝加哥", selectedId);
  options += timezoneOption("America/Denver", "美国山区 · 丹佛", selectedId);
  options += timezoneOption("America/Los_Angeles", "美国西部 · 洛杉矶", selectedId);
  options += timezoneOption("Australia/Sydney", "澳大利亚 · 悉尼", selectedId);
  options += timezoneOption("Pacific/Auckland", "新西兰 · 奥克兰", selectedId);
  options += timezoneOption("Etc/UTC", "协调世界时（UTC）", selectedId);
  return options;
}

void drawSetupScreen(TFT_eSPI &tft, const String &ssid, const String &reason) {
  tft.fillScreen(TFT_BLACK);
  tft.setTextDatum(TC_DATUM);
  tft.setTextColor(TFT_WHITE, TFT_BLACK);
  tft.drawString("SETUP MODE", 120, 24, 4);
  tft.setTextColor(0x8C71, TFT_BLACK);
  tft.drawString(reason, 120, 63, 2);
  tft.setTextColor(TFT_WHITE, TFT_BLACK);
  tft.drawString(ssid, 120, 94, 2);
  tft.setTextColor(0x8C71, TFT_BLACK);
  tft.drawString("Password", 120, 121, 2);
  tft.setTextColor(TFT_WHITE, TFT_BLACK);
  tft.drawString(kSetupPassword, 120, 142, 2);
  tft.setTextColor(0x3F67, TFT_BLACK);
  tft.drawString("192.168.4.1", 120, 178, 4);
  tft.setTextColor(0x8C71, TFT_BLACK);
  tft.drawString("Open in browser", 120, 214, 2);
  tft.setTextDatum(TL_DATUM);
}

String buildSetupPage(const WidgetConfig &config) {
  String networkOptions;
  const int networkCount = WiFi.scanNetworks();
  for (int index = 0; index < networkCount; index++) {
    const String ssid = WiFi.SSID(index);
    networkOptions += F("<option value=\"");
    networkOptions += htmlEscape(ssid);
    networkOptions += F("\">");
    networkOptions += String(WiFi.RSSI(index));
    networkOptions += F(" dBm</option>");
  }
  WiFi.scanDelete();

  String page;
  page.reserve(7000 + networkOptions.length());
  page += F(R"HTML(<!doctype html><html lang="zh-CN"><head>
<meta charset="utf-8"><meta name="viewport" content="width=device-width,initial-scale=1">
<title>Codex Widget Setup</title><style>
:root{color-scheme:dark;font-family:-apple-system,BlinkMacSystemFont,"Segoe UI",sans-serif}
body{margin:0;background:#090b10;color:#f5f7fa}.wrap{max-width:560px;margin:auto;padding:28px 20px 48px}
h1{font-size:28px;margin:0 0 8px}.sub{color:#9299a6;margin:0 0 28px}.card{background:#151922;border:1px solid #272d3a;border-radius:18px;padding:20px}
label{display:block;font-size:13px;color:#aeb5c2;margin:17px 0 7px}input,select{box-sizing:border-box;width:100%;border:1px solid #353d4d;border-radius:11px;background:#0d1016;color:#fff;padding:12px;font-size:16px}
.hint{font-size:12px;color:#7f8795;margin-top:6px}.row{display:grid;grid-template-columns:1fr 1fr;gap:12px}.check{display:flex;gap:9px;align-items:center;color:#aeb5c2;font-size:13px;margin-top:12px}.check input{width:auto}
button{width:100%;border:0;border-radius:12px;background:#36d17c;color:#07130c;font-weight:700;font-size:16px;padding:14px;margin-top:24px}.foot{text-align:center;color:#69717f;font-size:12px;margin-top:18px}
@media(max-width:480px){.row{grid-template-columns:1fr}}
</style></head><body><main class="wrap"><h1>Codex Widget</h1><p class="sub">配置网络和本地数据桥</p><form class="card" method="post" action="/save">
<label>Wi-Fi 名称</label><input name="ssid" list="networks" required maxlength="64" value=")HTML");
  page += htmlEscape(config.wifiSsid);
  page += F(R"HTML("><datalist id="networks">)HTML");
  page += networkOptions;
  page += F(R"HTML(</datalist><label>Wi-Fi 密码</label><input name="password" type="password" maxlength="64" autocomplete="new-password"><div class="hint">同一 Wi-Fi 留空会保留原密码；新网络留空表示开放网络。</div>
<label>Codex Bridge URL</label><input name="bridge" type="url" required maxlength="180" value=")HTML");
  page += htmlEscape(config.bridgeUrl);
  page += F(R"HTML(" placeholder="http://192.168.1.100:8787/api/status"><div class="hint">填写 Mac 的局域网地址，不能使用 localhost。</div>
<div class="row"><div><label>时区</label><select name="timezone" required>)HTML");
  page += timezoneOptions(config.timezoneId);
  page += F(R"HTML(</select></div><div><label>刷新间隔（秒）</label><input name="poll" type="number" min="2" max="60" value=")HTML");
  page += String(config.pollIntervalSeconds);
  page += F(R"HTML("></div></div><button type="submit">保存并重启</button></form><p class="foot">密码保存在设备 NVS；Codex 登录凭证始终留在 Mac。</p></main></body></html>)HTML");
  return page;
}
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

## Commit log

2026-08-27 fix: refresh reset countdown after time sync
    [main.cpp]
2026-08-27 fix: make ESP32 enclosure rails manifold
    [back-smoke-petg-v7-manifold.stl, codex_widget_enclosure.scad]
2026-08-27 feat: add mesh and enclosure validation
2026-08-27 chore: add audio timing samples
2026-08-27 feat: add graffiti idle flip clock
    [main.cpp]
2026-09-06 feat: improve HH:MM:SS flip clock and add bilingual docs
    [main.cpp]
